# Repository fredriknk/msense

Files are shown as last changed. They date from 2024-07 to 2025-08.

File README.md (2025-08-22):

# Methanesense

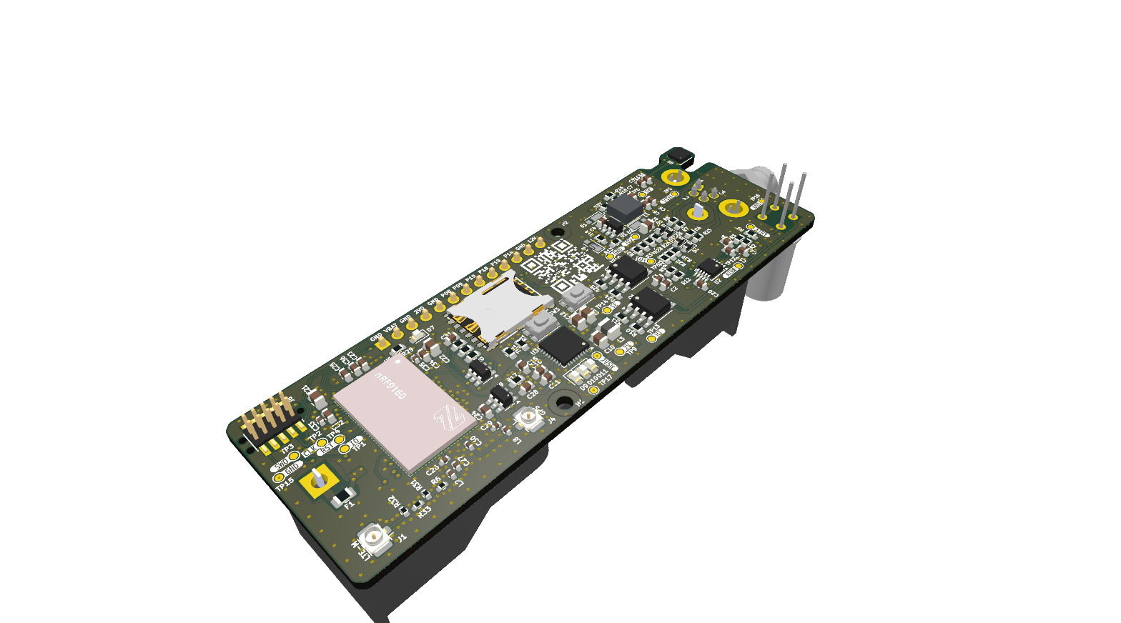
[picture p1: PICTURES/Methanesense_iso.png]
HEADER
 <!-- 3D rendered pretty view -->

Open Source hardware kicad source files for a NRF9160 based methane sensor utilizing MOX sensor.

Low power design with about 60ua average current consumption measuring Methane, temp, pressure and humidity every 30 seconds, averaging values over 5 minute samples, and transmitting 11 readings every 55 minutes. estimated battery life is 4.5 years from a 3200mah  18650 liion cell

It has an option for a GPS if necessary, but this will cause reduced battery life. 

[Assembly IBOM](https://htmlpreview.github.io/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) <!-- Interactive BOM PDF -->

[PCB layout](./DOCUMENTATION/Methanesense_board_prints.pdf) <!-- PDFs of boards -->

[SCHEMATIC](./DOCUMENTATION/Methanesense_schematic.pdf) <!-- Schematic PDFs -->

## FRONT
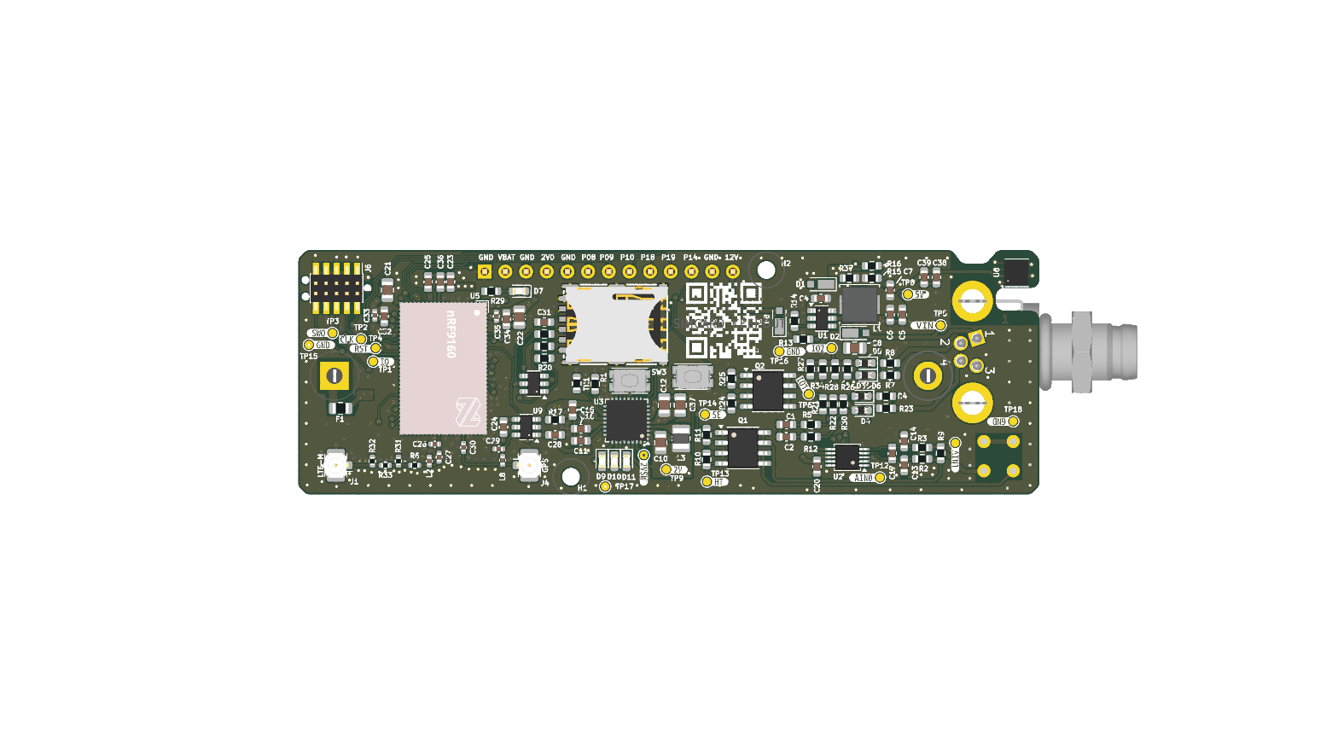
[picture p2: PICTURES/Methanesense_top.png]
Front


## BACK
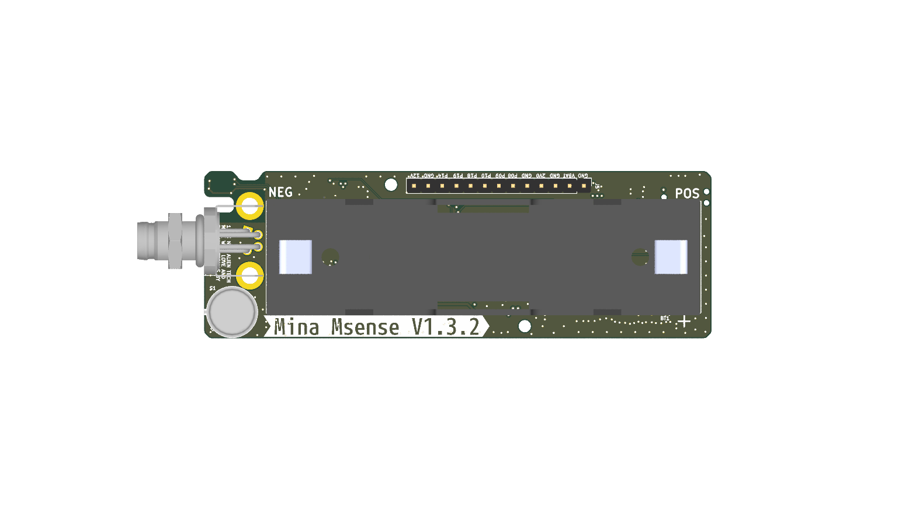
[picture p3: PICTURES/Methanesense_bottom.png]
Back


## SIDE
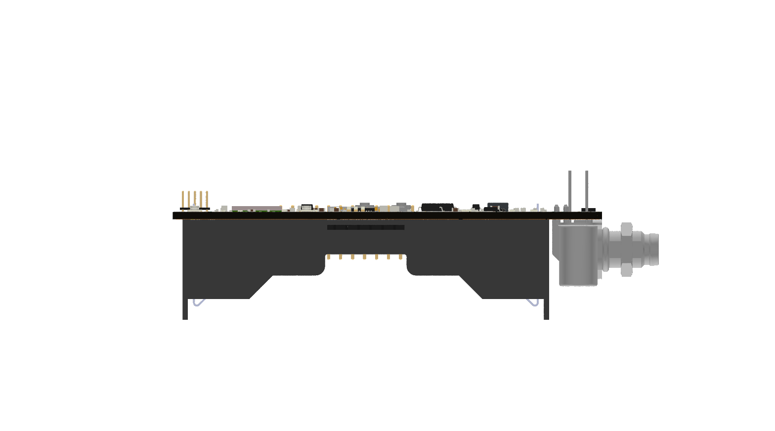
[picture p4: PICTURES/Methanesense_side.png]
Side


## Enclosure
Enclosure proposal. Simple 3d printed design snap lock, potential for epoxy fill for moisture resistance. But for now i just coat them in PLASTIK 70 conformal coating by Kontakt Chemie. DO REMEMBER TO SEAL SENSOR HOLES!!!

When 3d printing the enclosure, modify the two boxes in the sensor holes to be printed with gyroid infill with no walls or top/bottom to create the mesh. Enclosure files are in the [3D_MODEL](./3D_MODEL/) folder.

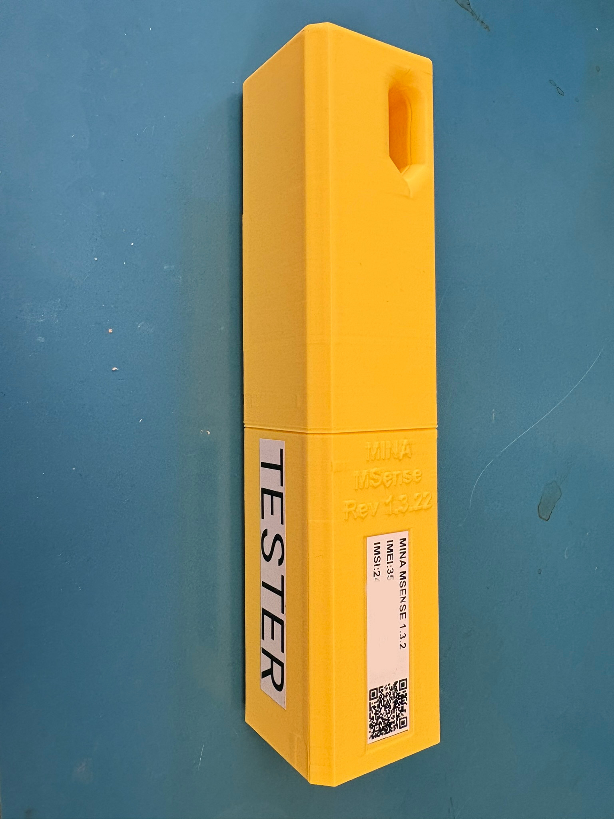
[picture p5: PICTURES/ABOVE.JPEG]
Enclosure

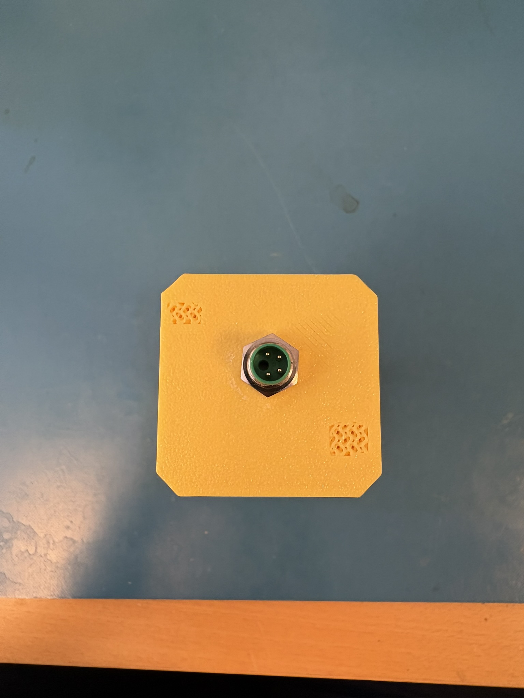
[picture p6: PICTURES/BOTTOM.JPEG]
Bottom_enc


## Documentation

[NRF9160SOC](./DOCUMENTATION/Datasheets/nRF9160_PS_v2.0.pdf)

[ADC](./DOCUMENTATION/Datasheets/ads1113.pdf)

[Temp/press/humidity sensor](./DOCUMENTATION/Datasheets/bst-bme680-ds001.pdf)

[Powersupply PMIC](./DOCUMENTATION/Datasheets/nPM1300_PS_v1.0.pdf)

[MOX Sensor](./DOCUMENTATION/Datasheets/tgs8410_product_infomation(en)_rev05.pdf)

# Before major commmits
Remember to run generate_outputs.bat/sh
to update the outputs and pictures.
readmetemplate

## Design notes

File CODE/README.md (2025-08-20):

The rust firmware for the sensor is located in the [Msense-firmware](https://github.com/fredriknk/msense-firmware) repository.

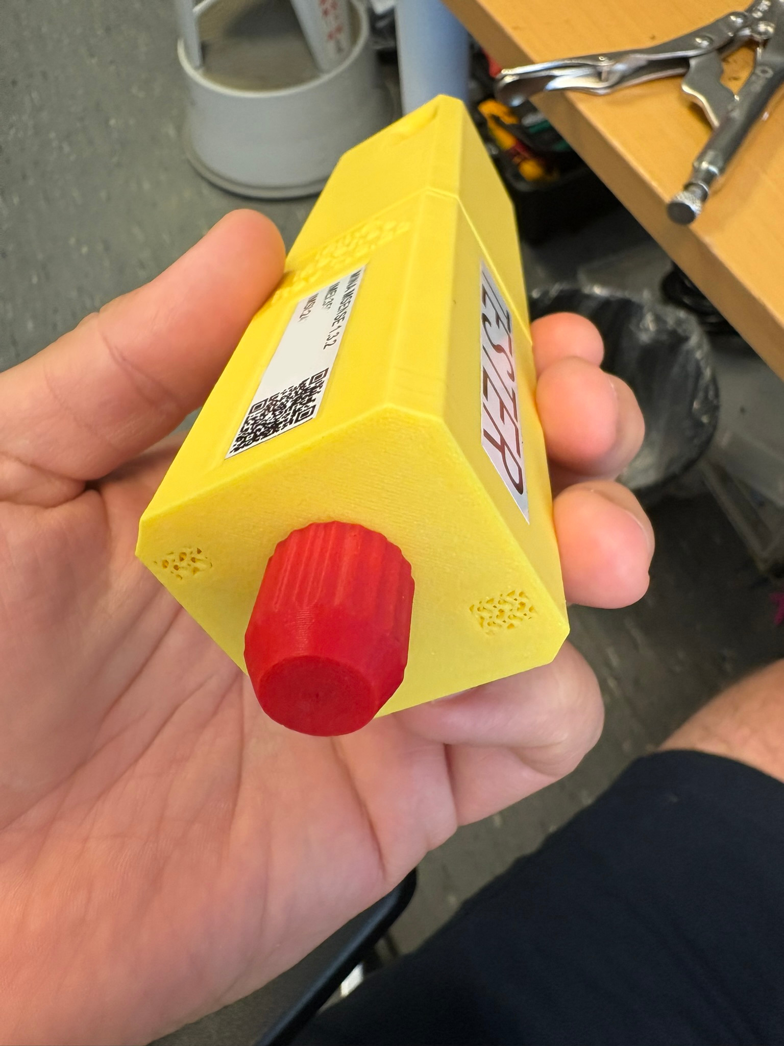
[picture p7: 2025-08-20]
PICTURES/CAP.JPEG

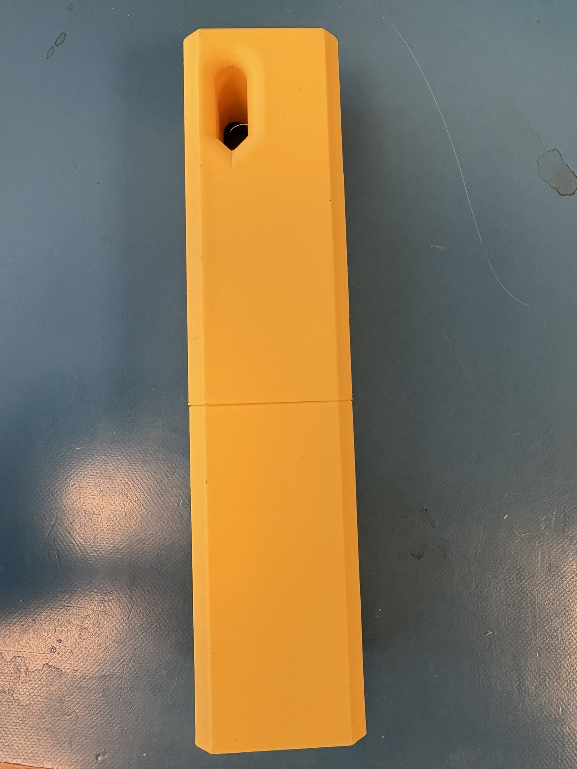
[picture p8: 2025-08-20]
PICTURES/SIDE.JPEG

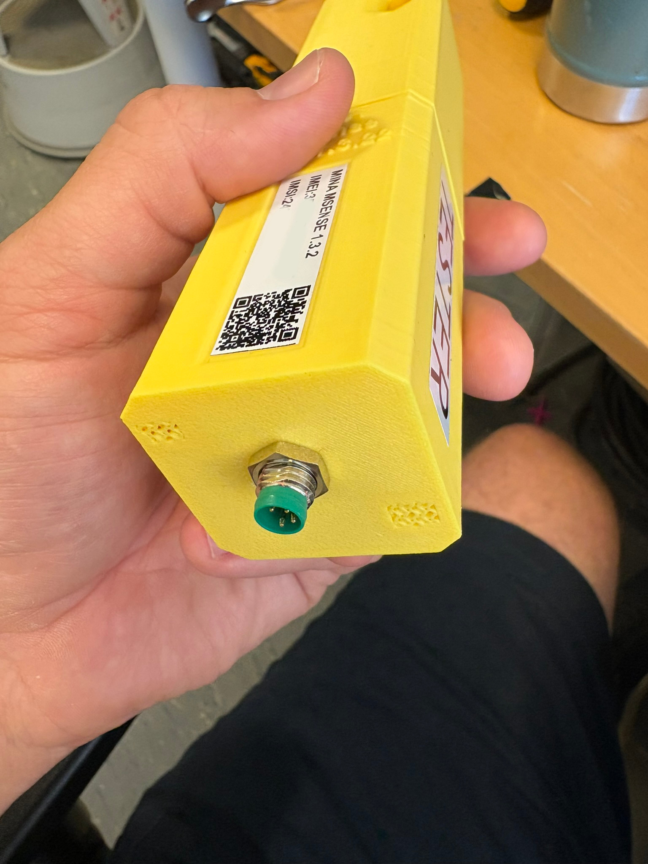
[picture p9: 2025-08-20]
PICTURES/CONNECTOR.JPEG

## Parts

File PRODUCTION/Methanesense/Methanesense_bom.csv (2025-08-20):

Refs | Value | Footprint | Qty | Manufacturer | MPN | Datasheet | DNP
AE1 | 2361492-1 |  | 1 |  | 2361492-1 | ~ | DNP
AE2 | YCGO009AA |  | 1 |  |  | ~ | DNP
BAT1 | 18650-3500mAH |  | 1 |  |  | ~ | DNP
BT1 | BH-18650-PC2 | Methanesense:BatteryHolder_MPD_BH-18650-PC2 | 1 |  | BH-18650-PC2 | ~
C1,C2,C4,C13,C14,C32,C34,C36,C38 | 0.1uF | Capacitor_SMD:C_0603_1608Metric | 9 |  |  | ~
C5-C7,C15,C23,C25 | 4.7uF | Capacitor_SMD:C_0603_1608Metric | 6 |  |  | ~
C8 | 2.2uF | Capacitor_SMD:C_0805_2012Metric | 1 |  |  | ~
C10,C12,C37 | 10uF | Capacitor_SMD:C_0805_2012Metric | 3 |  |  | ~
C11,C16,C17,C20,C28,C31,C39 | 1uF | Capacitor_SMD:C_0603_1608Metric | 7 |  |  | ~ | DNP
C21,C22 | 47uF | Capacitor_SMD:C_0805_2012Metric | 2 |  |  | ~
C24 | 1nF | Capacitor_SMD:C_0603_1608Metric | 1 |  |  | ~
C26,C27,C33,C35 | 15pF | Methanesense:C_0402_1005Metric_Sqr | 4 |  | VJ0402D150FXCAJ | ~
C29,C30 | 56pF | Methanesense:C_0402_1005Metric_Sqr | 2 |  | CBR04C560F1GAC | ~
D1,D2,D8 | MSS1P3L-M3/89A | Diode_SMD:D_MicroSMP_AK | 3 |  | MSS1P3L-M3/89A | ~
D3-D6 | SD0603S040S0R2 | Diode_SMD:D_0603_1608Metric | 4 |  | SD0603S040S0R2 | ~ | DNP
D7 | LG L29K-G2J1-24-Z | LED_SMD:LED_0603_1608Metric | 1 |  | LG L29K-G2J1-24-Z | https://look.ams-osram.com/m/19ee86b3ae0ee95b/original/LG-L29K.pdf
D9-D11 | LED | LED_SMD:LED_0603_1608Metric | 3 |  | LG L29K-G2J1-24-Z | ~
F1 | 0805L110WR | Fuse:Fuse_0805_2012Metric | 1 |  | 0805L110WR | ~
J1,J4 | HIROSE ELECTRIC U.FL-R-SMT-1 | Methanesense:U.FL_Hirose_U.FL-R-SMT-1_Vertical | 2 |  | U.FL-R-SMT-1 | ~
J2 | IEC61076-2_M8_A-coding_01x04_Receptacle_Shielded | Methanesense:STEWART_SS-12800-004_M8_04_Socket_Right_Angle | 1 |  | SS-12800-004
J3 | 693043020611 | Methanesense:693043020611 | 1 |  | 693043020611
J5 | Conn_01x13_Pin | Connector_PinHeader_2.54mm:PinHeader_1x13_P2.54mm_Vertical | 1 |  |  | ~
J6 | JLINK | esprelay:SEXY_pinpogo | 1 |  | BD125-10-A-0305-0580-L-B | ~
L1 | 22uH | Methanesense:L_Abracon_AMDLA4020S | 1 |  | AMDLA4020S-220MT | ~
L2 | 39NH | Methanesense:C_0402_1005Metric_Sqr | 1 |  | LQW15AN39NJ8ZD | ~
L3 | 2.2uH | Inductor_SMD:L_1008_2520Metric | 1 |  | CVH252009-2R2M | ~
L8 | 68 nH | Methanesense:C_0402_1005Metric_Sqr | 1 |  | LQW15AN68NG0ZD | ~
Q1,Q2 | FDS6898A | Package_SO:SOIC-8_3.9x4.9mm_P1.27mm | 2 |  | FDS6898A | https://www.onsemi.com/pub/Collateral/FDS6892A-D.pdf
R1 | 68k | Resistor_SMD:R_0603_1608Metric | 1 |  |  | ~
R2,R3,R5,R12 | 470R | Resistor_SMD:R_0603_1608Metric | 4 |  |  | ~
R4,R8 | 1k | Resistor_SMD:R_0603_1608Metric | 2 |  |  | ~ | DNP
R6,R31-R33 | 0R | Resistor_SMD:R_0402_1005Metric | 4 |  |  | ~ | DNP
R7,R21,R22,R26-R28,R30,R34,R37 | 0R | Resistor_SMD:R_0603_1608Metric | 9 |  |  | ~ | DNP
R9 | 12k | Resistor_SMD:R_0603_1608Metric | 1 |  |  | ~
R10,R11,R17,R24,R25 | 1M | Resistor_SMD:R_0603_1608Metric | 5 |  |  | ~
R13 | 56k | Resistor_SMD:R_0603_1608Metric | 1 |  |  | ~
R14,R16,R23 | 10k | Resistor_SMD:R_0603_1608Metric | 3 |  |  | ~
R15 | 15k | Resistor_SMD:R_0603_1608Metric | 1 |  |  | ~
R18-R20 | 100R | Resistor_SMD:R_0603_1608Metric | 3 |  |  | ~
R29 | 150R | Resistor_SMD:R_0603_1608Metric | 1 |  |  | ~
S1 | TGS8410 | Methanesense:TGS8410 | 1 |  | TGS8410 | https://www.figarosensor.com/product/docs/tgs8410_product%20information%28fusa%29_rev05.pdf
SW1,SW3 | KMR223NGLFG | Methanesense:SW_Push_1P1T_NO_CK_KMR2 | 2 |  | KMR223GLFG | ~
TH1 | 10k NTC | Resistor_SMD:R_0603_1608Metric | 1 |  | NTCG163JF103FT1 | ~
TP1 | SWDIO | TestPoint:TestPoint_Pad_D1.0mm | 1 |  |  | ~ | DNP
TP2 | SWDCLK | TestPoint:TestPoint_Pad_D1.0mm | 1 |  |  | ~ | DNP
TP3 | SWO | TestPoint:TestPoint_Pad_D1.0mm | 1 |  |  | ~ | DNP
TP4 | RST | TestPoint:TestPoint_Pad_D1.0mm | 1 |  |  | ~ | DNP
TP5 | VIN | TestPoint:TestPoint_Pad_D1.0mm | 1 |  |  | ~ | DNP
TP6 | IO1 | TestPoint:TestPoint_Pad_D1.0mm | 1 |  |  | ~ | DNP
TP7 | IO2 | TestPoint:TestPoint_Pad_D1.0mm | 1 |  |  | ~ | DNP
TP8 | 5V | TestPoint:TestPoint_Pad_D1.0mm | 1 |  |  | ~ | DNP
TP9 | 2V | TestPoint:TestPoint_Pad_D1.0mm | 1 |  |  | ~ | DNP
TP10 | I1 | TestPoint:TestPoint_Pad_D1.0mm | 1 |  |  | ~ | DNP
TP11 | AIN1 | TestPoint:TestPoint_Pad_D1.0mm | 1 |  |  | ~ | DNP
TP12 | AIN0 | TestPoint:TestPoint_Pad_D1.0mm | 1 |  |  | ~ | DNP
TP13 | SEN | TestPoint:TestPoint_Pad_D1.0mm | 1 |  |  | ~ | DNP
TP14 | HEAT | TestPoint:TestPoint_Pad_D1.0mm | 1 |  |  | ~ | DNP
TP15-TP18 | GND | TestPoint:TestPoint_Pad_D1.0mm | 4 |  |  | ~ | DNP
U1 | LV2862XDDC | Package_TO_SOT_SMD:SOT-23-6 | 1 |  | LV2862XLVDDCR | https://www.ti.com/lit/ds/symlink/lv2862.pdf
U2 | ADS1115IDGST | Package_SO:TSSOP-10_3x3mm_P0.5mm | 1 |  | ADS1115IDGSR | http://www.ti.com/lit/ds/symlink/ads1113.pdf
U3 | nPM1300-QEXX | Methanesense:QFN-32-1EP_5x5mm_P0.5mm_EP3.6x3.6mm_ThermalVias | 1 |  | nPM1300-QEAA-R7 | https://docs.nordicsemi.com/bundle/ps_npm1300
U5 | nRF9160-SICA | Methanesense:LGA_9160_16.0x10.5mm | 1 |  | nRF9160-SICA-B1A-R7 | https://docs.nordicsemi.com/bundle/ps_nrf9160/page/nRF9160_html5_keyfeatures.html
U6 | BME680 | Package_LGA:Bosch_LGA-8_3x3mm_P0.8mm_ClockwisePinNumbering | 1 |  | BME680 | https://ae-bst.resource.bosch.com/media/_tech/media/datasheets/BST-BME680-DS001.pdf
U8 | USBLC6-4SC6 | Package_TO_SOT_SMD:SOT-23-6 | 1 |  | USBLC6-4SC6 | https://www.st.com/resource/en/datasheet/usblc6-4.pdf
U9 | TPS22917DBV | Package_TO_SOT_SMD:SOT-23-6 | 1 |  | TPS22917DBVR | http://www.ti.com/lit/ds/symlink/tps22917.pdf

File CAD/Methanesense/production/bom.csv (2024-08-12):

Designator | Footprint | Quantity | Value | LCSC Part #
AE1 | XCVR_NN02-220 | 1 | NN02-220 | NN02-220
C1, C2 | 0603 | 2 | 1.7pF | GJM1555C1H1R7WB01
C10, C12, C37 | 0805 | 3 | 10uF
C11, C20, C28, C31, C39, C7, C8, C9 | 0603 | 8 | 1uF
C13, C14, C19, C32, C34, C36, C38 | 0603 | 7 | 0.1uF
C15 | 0603 | 1 | 4.7uF
C16 | 0603 | 1 | 1uF
C21, C22 | 0805 | 2 | 47uF
C23, C25 | 0603 | 2 | 4.7uF
C24 | 0603 | 1 | 1nF
C26, C27, C33, C35 | 0402 | 4 | 15pF | VJ0402D150FXCAJ
C29, C30 | 0402 | 2 | 56pF | CBR04C560F1GAC
C3, C6 | 0603 | 2 | 47pF
C4 | 0603 | 1 | 8.5pF | GJM1555C1H8R5WB01
D10, D11, D5, D6, D9 | 0603 | 5 | LED | LG L29K-G2J1-24-Z
F1 | 0805 | 1 | 0805L110WR | 0805L110WR
J1 | USB_C_Receptacle_HCTL_HC-TYPE-C-16P-01A | 1 | USB_C_Receptacle_USB2.0_14P | 12402012E212A
J3 | 693043020611 | 1 | 693043020611 | 693043020611
J4 | U.FL_Hirose_U.FL-R-SMT-1_Vertical | 1 | HIROSE ELECTRIC U.FL-R-SMT-1 | U.FL-R-SMT-1
L1 | 0603 | 1 | 2.3nH | LQW15AN2N3G80
L2 | 0402 | 1 | 39NH | LQW15AN39NJ8ZD
L3 | 1008 | 1 | 2.2uH | CVH252009-2R2M
L5 | 0603 | 1 | 7.5NH | LQW15AN7N5G80
L6 | 0603 | 1 | 1.6nH | LQW15AN1N6C80
L8 | 0402 | 1 | 68 nH | LQW15AN68NG0ZD
Q1, Q2 | SOIC-8_3.9x4.9mm_P1.27mm | 2 | FDS6898A | FDS6898A
R1 | 0603 | 1 | 68k
R10, R11, R17, R24, R25 | 0603 | 5 | 1M
R18, R19, R20, R22, R23 | 0603 | 5 | 100R
R2, R3 | 0603 | 2 | 470R
R5 | 0603 | 1 | 0R
SW3 | SW_Push_1P1T_NO_CK_KMR2 | 1 | KMR223NGLFG | KMR223NGLFG
TH1 | 0603 | 1 | 10k NTC | NTCG163JF103FT1
U2 | TSSOP-10_3x3mm_P0.5mm | 1 | ADS1115IDGS | ADS1115IDGS
U3 | QFN-32-1EP_5x5mm_P0.5mm_EP3.6x3.6mm_ThermalVias | 1 | nPM1300-QEXX | nPM1300-QEAA-R7
U4 | SOT-23-5 | 1 | AP7331-20WG-7 | AP7331-20WG-7
U5 | LGA_9160_16.0x10.5mm | 1 | nRF9160-SICA | nRF9160-SICA-B1A-R7
U6 | Bosch_LGA-8_3x3mm_P0.8mm_ClockwisePinNumbering | 1 | BME680 | BME680
U7 | QFN-16-1EP_4x4mm_P0.65mm_EP2.1x2.1mm | 1 | FT230XQ | FT230XQ
U8 | SOT-23-6 | 1 | USBLC6-4SC6 | USBLC6-4SC6
U9 | SOT-23-6 | 1 | TPS22917DBV | TPS22917DBVR

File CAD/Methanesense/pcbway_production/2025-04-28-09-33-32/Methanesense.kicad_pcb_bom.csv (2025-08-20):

Designator | Quantity | Value | Footprint | Package | MPN | DNP | Mount_Type | Description | MF | Description_1 | MOUNT | IR | Check_prices | VALUE | Price | PART-NUMBER | SnapEDA_Link | DATASHEET-URL | MP | WORKING-VOLTAGE | PINS | TYPE | GERDER | Availability
BT1 | 1 | BH-18650-PC2 | BatteryHolder_MPD_BH-18650-PC2 |  | BH-18650-PC2 |  | tht | Single-cell battery
C1, C13, C14, C2, C32, C34, C36, C38, C4 | 9 | 0.1uF | C_0603_1608Metric |  |  |  | smt | Unpolarized capacitor
C10, C12, C37 | 3 | 10uF | C_0805_2012Metric |  |  |  | smt | Unpolarized capacitor
C11, C16, C20, C28, C31, C39 | 6 | 1uF | C_0603_1608Metric |  |  |  | smt | Unpolarized capacitor
C15, C23, C25, C5, C6, C7 | 6 | 4.7uF | C_0603_1608Metric |  |  |  | smt | Unpolarized capacitor
C17 | 1 | 1uF | C_0603_1608Metric |  |  | Yes | smt | Unpolarized capacitor
C21, C22 | 2 | 47uF | C_0805_2012Metric |  |  |  | smt | Unpolarized capacitor
C24 | 1 | 1nF | C_0603_1608Metric |  |  |  | smt | Unpolarized capacitor
C26, C27, C33, C35 | 4 | 15pF | C_0402_1005Metric_Sqr |  | VJ0402D150FXCAJ |  | smt | RF
C29, C30 | 2 | 56pF | C_0402_1005Metric_Sqr |  | CBR04C560F1GAC |  | smt | RF
C8 | 1 | 2.2uF | C_0805_2012Metric |  |  |  | smt | Unpolarized capacitor
D1, D2, D8 | 3 | MSS1P3L-M3/89A | D_MicroSMP_AK |  | MSS1P3L-M3/89A |  | smt | Schottky diode
D10, D11, D9 | 3 | LED | LED_0603_1608Metric |  | LG L29K-G2J1-24-Z |  | smt | Light emitting diode
D3, D4, D6 | 3 | SD0603S040S0R2 | D_0603_1608Metric |  | SD0603S040S0R2 |  | smt | Schottky diode
D5 | 1 | SD0603S040S0R2 | D_0603_1608Metric |  | SD0603S040S0R2 | Yes | smt | Schottky diode
D7 | 1 | LG L29K-G2J1-24-Z | LED_0603_1608Metric |  | LG L29K-G2J1-24-Z |  | smt | LED Green
F1 | 1 | 0805L110WR | Fuse_0805_2012Metric |  | 0805L110WR |  | smt | Resettable fuse, polymeric positive temperature coefficient
J1, J4 | 2 | HIROSE ELECTRIC U.FL-R-SMT-1 | U.FL_Hirose_U.FL-R-SMT-1_Vertical |  | U.FL-R-SMT-1 |  | smt | coaxial connector (BNC, SMA, SMB, SMC, Cinch/RCA, LEMO, ...)
J2 | 1 | IEC61076-2_M8_A-coding_01x04_Receptacle_Shielded | STEWART_SS-12800-004_M8_04_Socket_Right_Angle |  | SS-12800-004 |  | tht | IEC 61076-2 4 ways shielded M8 A-coding receptacle connector
J3 | 1 | 693043020611 | 693043020611 |  | 693043020611 |  | smt |  | Wurth Electronics | CardConnector_SMT_NanoSIM_Push & Pull_6pins | SMT | 1A | https://www.snapeda.com/parts/693043020611/Wurth+Electronics/view-part/?ref=eda | 693043020611 | None | 693043020611 | https://www.snapeda.com/parts/693043020611/Wurth+Electronics/view-part/?ref=snap | https://www.we-online.com/redexpert/spec/693043020611?ae | 693043020611 | 15V(AC) | 6 | Push & Push | Socket | In Stock
J5 | 1 | Conn_01x13_Pin | PinHeader_1x13_P2.54mm_Vertical |  |  |  | tht | Generic connector, single row, 01x13, script generated
J6 | 1 | JLINK | SEXY_pinpogo |  | BD125-10-A-0305-0580-L-B |  | smt | HEADER DUAL 1.27MM VERT SMT 10PO
L1 | 1 | 22uH | L_Abracon_AMDLA4020S |  | AMDLA4020S-220MT |  | smt | Inductor
L2 | 1 | 39NH | C_0402_1005Metric_Sqr |  | LQW15AN39NJ8ZD |  | smt | 250mA 0.7OHM SMD RF
L3 | 1 | 2.2uH | L_1008_2520Metric |  | CVH252009-2R2M |  | smt
L8 | 1 | 68 nH | C_0402_1005Metric_Sqr |  | LQW15AN68NG0ZD |  | smt | RF
Q1, Q2 | 2 | FDS6898A | SOIC-8_3.9x4.9mm_P1.27mm |  | FDS6898A |  | smt | 9.4A Id, 20V Vds, Dual N-Channel MOSFET , 14mOhm Ron, SO-8
R1 | 1 | 68k | R_0603_1608Metric |  |  |  | smt | Resistor
R10, R11, R17, R24, R25 | 5 | 1M | R_0603_1608Metric |  |  |  | smt | Resistor
R12, R2, R3, R5 | 4 | 470R | R_0603_1608Metric |  |  |  | smt | Resistor
R13 | 1 | 56k | R_0603_1608Metric |  |  |  | smt | Resistor
R14, R16, R23 | 3 | 10k | R_0603_1608Metric |  |  |  | smt | Resistor
R15 | 1 | 15k | R_0603_1608Metric |  |  |  | smt | Resistor
R18, R19, R20 | 3 | 100R | R_0603_1608Metric |  |  |  | smt | Resistor
R21 | 1 | 0R | R_0603_1608Metric |  |  | Yes | smt | Resistor
R22 | 1 | 0R | R_0603_1608Metric |  |  | Yes | smt | Resistor
R26 | 1 | 0R | R_0603_1608Metric |  |  | Yes | smt | Resistor
R27, R30, R37, R7 | 4 | 0R | R_0603_1608Metric |  |  |  | smt | Resistor
R28 | 1 | 0R | R_0603_1608Metric |  |  | Yes | smt | Resistor
R29 | 1 | 150R | R_0603_1608Metric |  |  |  | smt | Resistor
R31 | 1 | 0R | R_0402_1005Metric |  |  | Yes | smt | Resistor
R32 | 1 | 0R | R_0402_1005Metric |  |  | Yes | smt | Resistor
R33, R6 | 2 | 0R | R_0402_1005Metric |  |  |  | smt | Resistor
R34 | 1 | 0R | R_0603_1608Metric |  |  | Yes | smt | Resistor
R4 | 1 | 1k | R_0603_1608Metric |  |  |  | smt | Resistor
R8 | 1 | 1k | R_0603_1608Metric |  |  | Yes | smt | Resistor
R9 | 1 | 12k | R_0603_1608Metric |  |  |  | smt | Resistor
S1 | 1 | TGS8410 | TGS8410 |  | TGS8410 |  | tht | MOX gas sensor
SW1, SW3 | 2 | KMR223NGLFG | SW_Push_1P1T_NO_CK_KMR2 |  | KMR223GLFG |  | smt | Push button switch, generic, two pins
TH1 | 1 | 10k NTC | R_0603_1608Metric |  | NTCG163JF103FT1 |  | smt | Temperature dependent resistor, negative temperature coefficient
TP1 | 1 | SWDIO | TestPoint_Pad_D1.0mm |  |  | Yes | tht | test point
TP10 | 1 | I1 | TestPoint_Pad_D1.0mm |  |  | Yes | tht | test point
TP11 | 1 | AIN1 | TestPoint_Pad_D1.0mm |  |  | Yes | tht | test point
TP12 | 1 | AIN0 | TestPoint_Pad_D1.0mm |  |  | Yes | tht | test point
TP13 | 1 | SEN | TestPoint_Pad_D1.0mm |  |  | Yes | tht | test point
TP14 | 1 | HEAT | TestPoint_Pad_D1.0mm |  |  | Yes | tht | test point
TP15 | 1 | GND | TestPoint_Pad_D1.0mm |  |  | Yes | tht | test point
TP16 | 1 | GND | TestPoint_Pad_D1.0mm |  |  | Yes | tht | test point
TP17 | 1 | GND | TestPoint_Pad_D1.0mm |  |  | Yes | tht | test point
TP18 | 1 | GND | TestPoint_Pad_D1.0mm |  |  | Yes | tht | test point
TP2 | 1 | SWDCLK | TestPoint_Pad_D1.0mm |  |  | Yes | tht | test point
TP3 | 1 | SWO | TestPoint_Pad_D1.0mm |  |  | Yes | tht | test point
TP4 | 1 | RST | TestPoint_Pad_D1.0mm |  |  | Yes | tht | test point
TP5 | 1 | VIN | TestPoint_Pad_D1.0mm |  |  | Yes | tht | test point
TP6 | 1 | IO1 | TestPoint_Pad_D1.0mm |  |  | Yes | tht | test point
TP7 | 1 | IO2 | TestPoint_Pad_D1.0mm |  |  | Yes | tht | test point
TP8 | 1 | 5V | TestPoint_Pad_D1.0mm |  |  | Yes | tht | test point
TP9 | 1 | 2V | TestPoint_Pad_D1.0mm |  |  | Yes | tht | test point
U1 | 1 | LV2862XDDC | SOT-23-6 |  | LV2862XLVDDCR |  | smt | 60V, 0.6A, stepdown, DC/DC converter, 770kHz
U2 | 1 | ADS1115IDGST | TSSOP-10_3x3mm_P0.5mm |  | ADS1115IDGSR |  | smt
U3 | 1 | nPM1300-QEXX | QFN-32-1EP_5x5mm_P0.5mm_EP3.6x3.6mm_ThermalVias |  | nPM1300-QEAA-R7 |  | smt | PMIC, LED Driver, Battery Charger, QFN-32
U5 | 1 | nRF9160-SICA | LGA_9160_16.0x10.5mm |  | nRF9160-SICA-B1A-R7 |  | smt
U6 | 1 | BME680 | Bosch_LGA-8_3x3mm_P0.8mm_ClockwisePinNumbering |  | BME680 |  | smt | 4-in-1 sensor, gas, humidity, pressure, temperature, I2C and SPI interface, 1.71-3.6V, LGA-8
U8 | 1 | USBLC6-4SC6 | SOT-23-6 |  | USBLC6-4SC6 |  | smt | Very low capacitance ESD protection diode, 4 data-line, SOT-23-6
U9 | 1 | TPS22917DBV | SOT-23-6 |  | TPS22917DBVR |  | smt | 1V to 5.5V, 2A, 80mΩ Ultra-Low Leakage Load Switch, SOT23-6

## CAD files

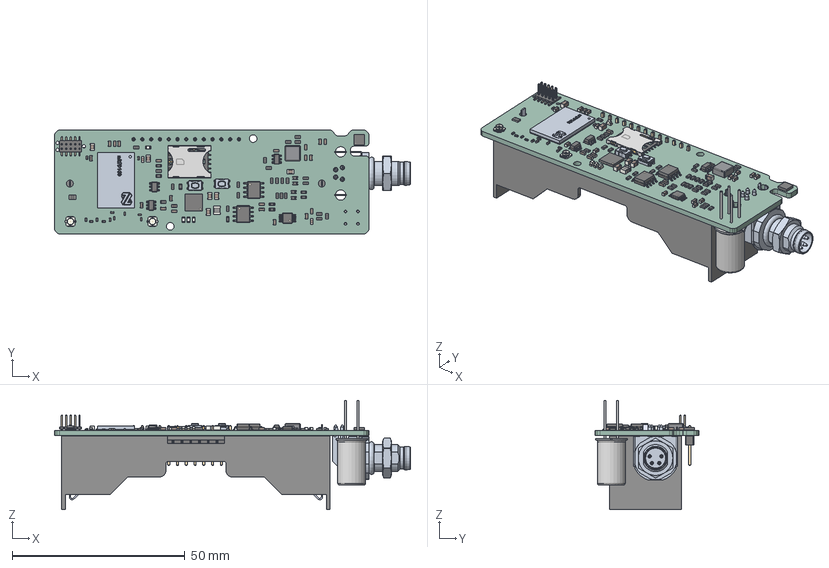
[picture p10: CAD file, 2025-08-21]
3D_MODEL/Methanesense.step
103.0 x 30.0 x 31.6 mm
C_0402_1005Metric x 8
R_0603_1608Metric x 32
SOIC-8_3.9x4.9mm_P1.27mm x 2
C_0603_1608Metric x 23
Bosch_LGA-8_3x3mm_P0.8mm_ClockwisePinNumbering
C_0805_2012Metric x 6
LED_0603_1608Metric x 4
PinHeader_2x05_P1.27mm_Vertical_SMD
KMR231GLFS x 2
R_0402_1005Metric x 4
SOT-23-6 x 3
D_0603_1608Metric x 4
Fuse_0805_2012Metric
U.FL_Hirose_U.FL-R-SMT-1_Vertical x 2
TSSOP-10_3x3mm_P0.5mm
693043020611_SHIELDING
Methanesense 1.55.1
L_Abracon_ASPIAIG-F4020
QFN-32-1EP_5x5mm_P0.5mm_EP3.45x3.45mm
L_1008_2520Metric
TGS8410 v2
BH-18650-PC--3DModel-STEP-56544
SS-12800-004_PART1
SS-12800-004_PART2
SS-12800-004_PART3
SS-12800-004_PART4
PinHeader_1x13_P2.54mm_Vertical
Methanesense_PCB

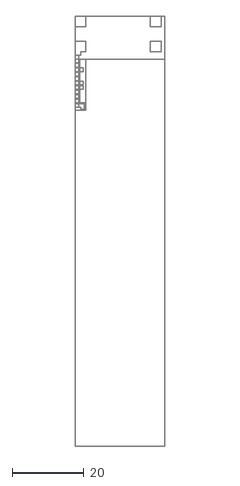
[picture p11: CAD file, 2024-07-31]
DOCUMENTATION/Antennadesign/Top.dxf
25.0 x 120.0

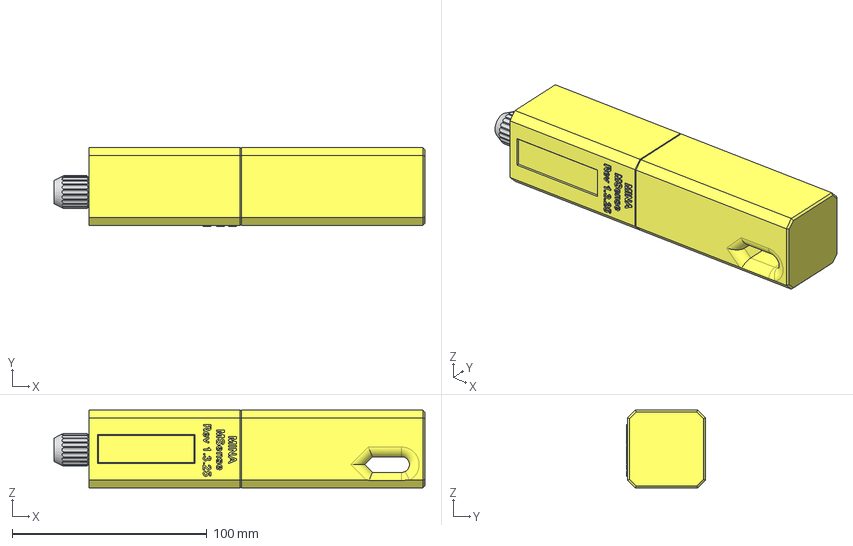
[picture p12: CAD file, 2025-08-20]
3D_MODEL/Enclosure_board_132 v26.step
190.6 x 40.5 x 40.0 mm
Case
m8_plug

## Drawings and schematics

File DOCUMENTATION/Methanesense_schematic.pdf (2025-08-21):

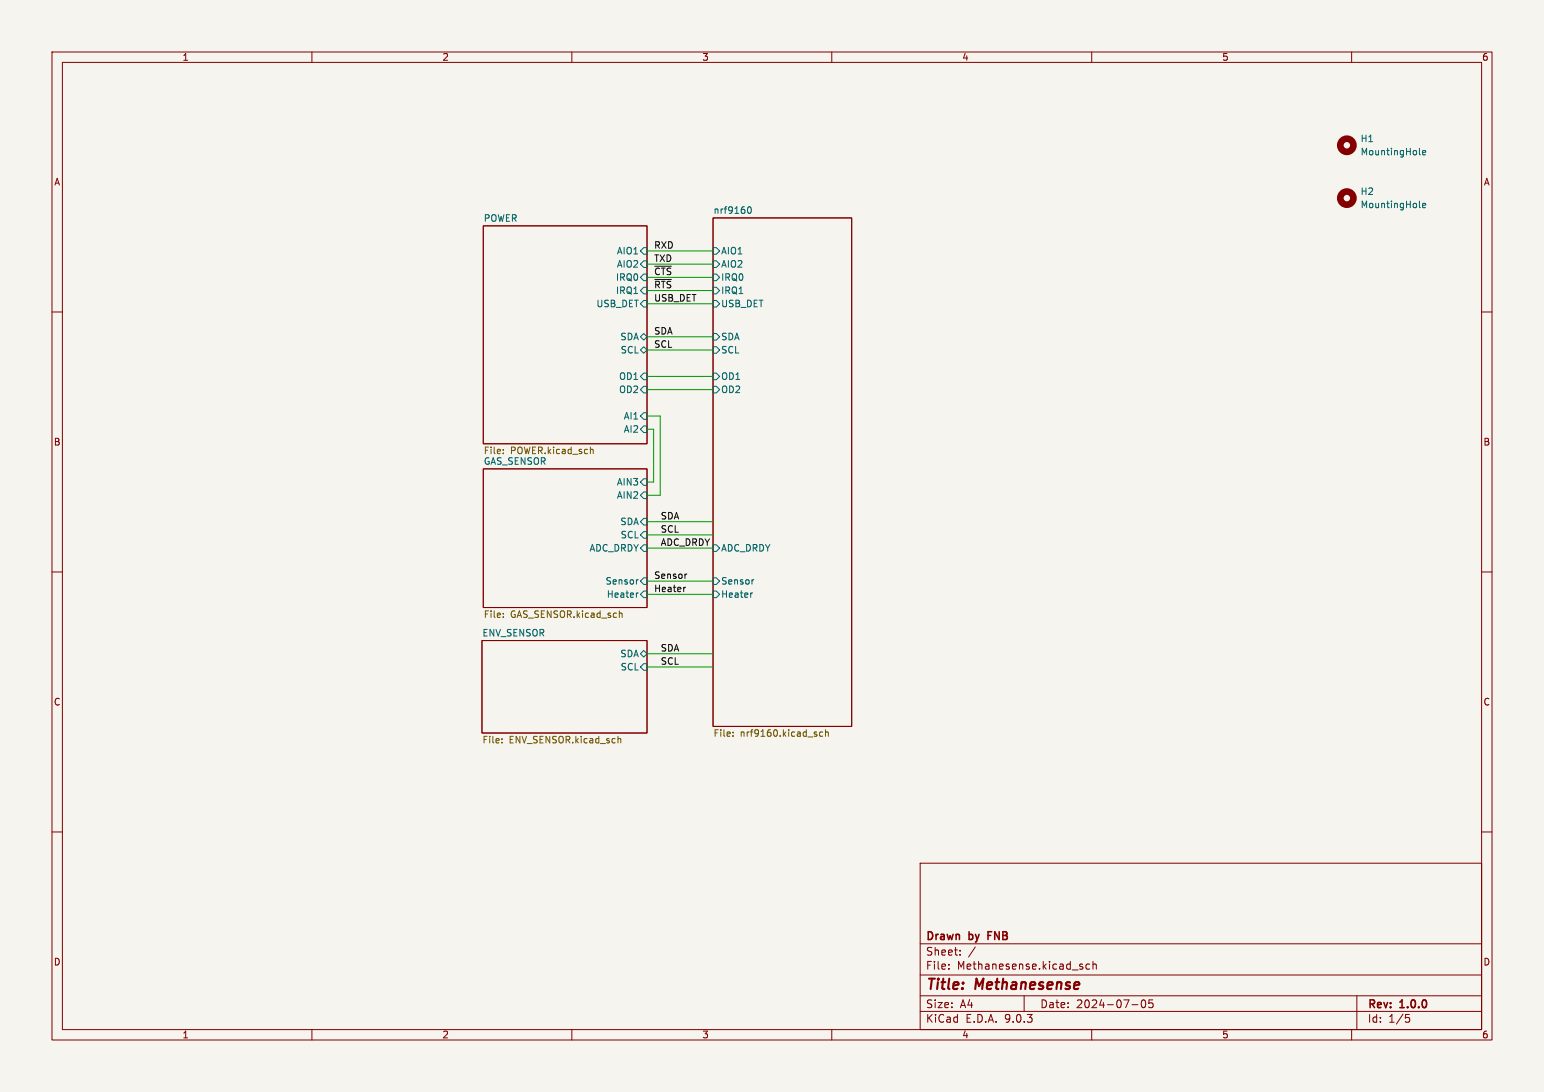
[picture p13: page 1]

H1 MountingHole H2 MountingHole Heater SCL Sensor ~{CTS} SDA USB_DET SCL SCL ADC_DRDY
nrf9160 File: nrf9160.kicad_sch
SDA RXD
SCL USB_DET AI1 AIO1 OD1 AI2 AIO2 OD2
SCL USB_DET OD1 OD2

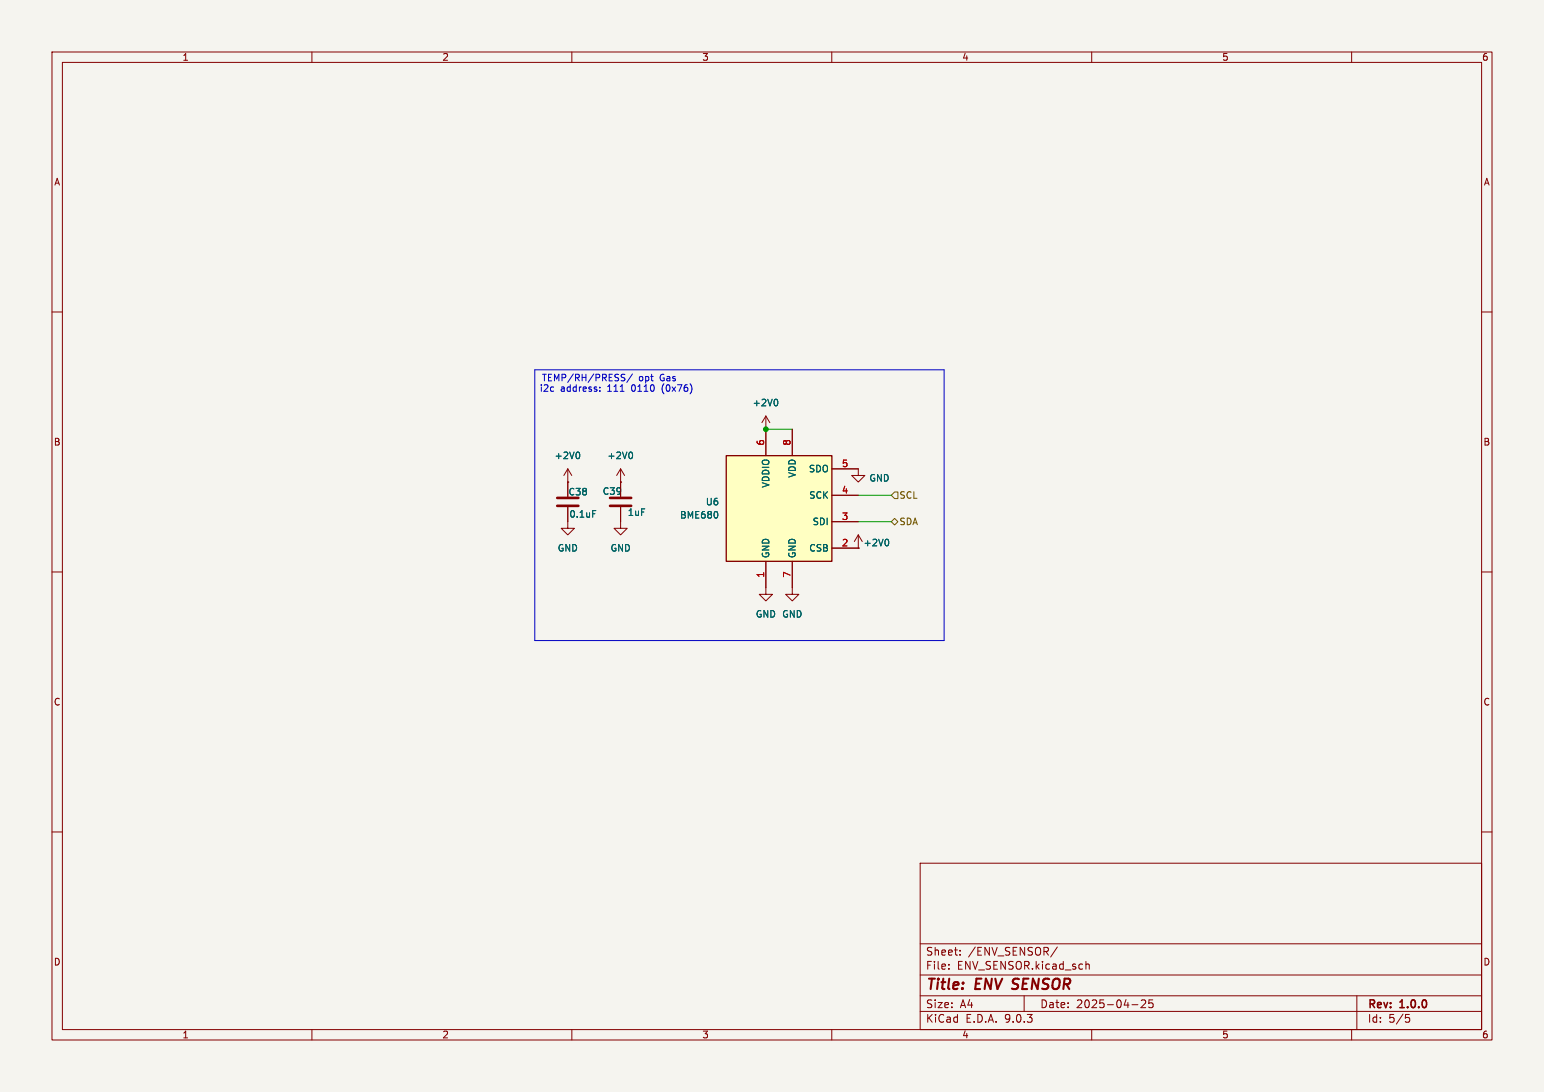
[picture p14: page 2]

7 SDO 5 SCK 4 SDI 3 CSB 2 U6 BME680 +2V0 +2V0 C39

7 SDO 5 SCK 4 SDI 3 CSB 2 +2V0 +2V0 C39

File: ENV_SENSOR.kicad_sch Sheet: /ENV_SENSOR/
Id: 5/5 Title: ENV SENSOR

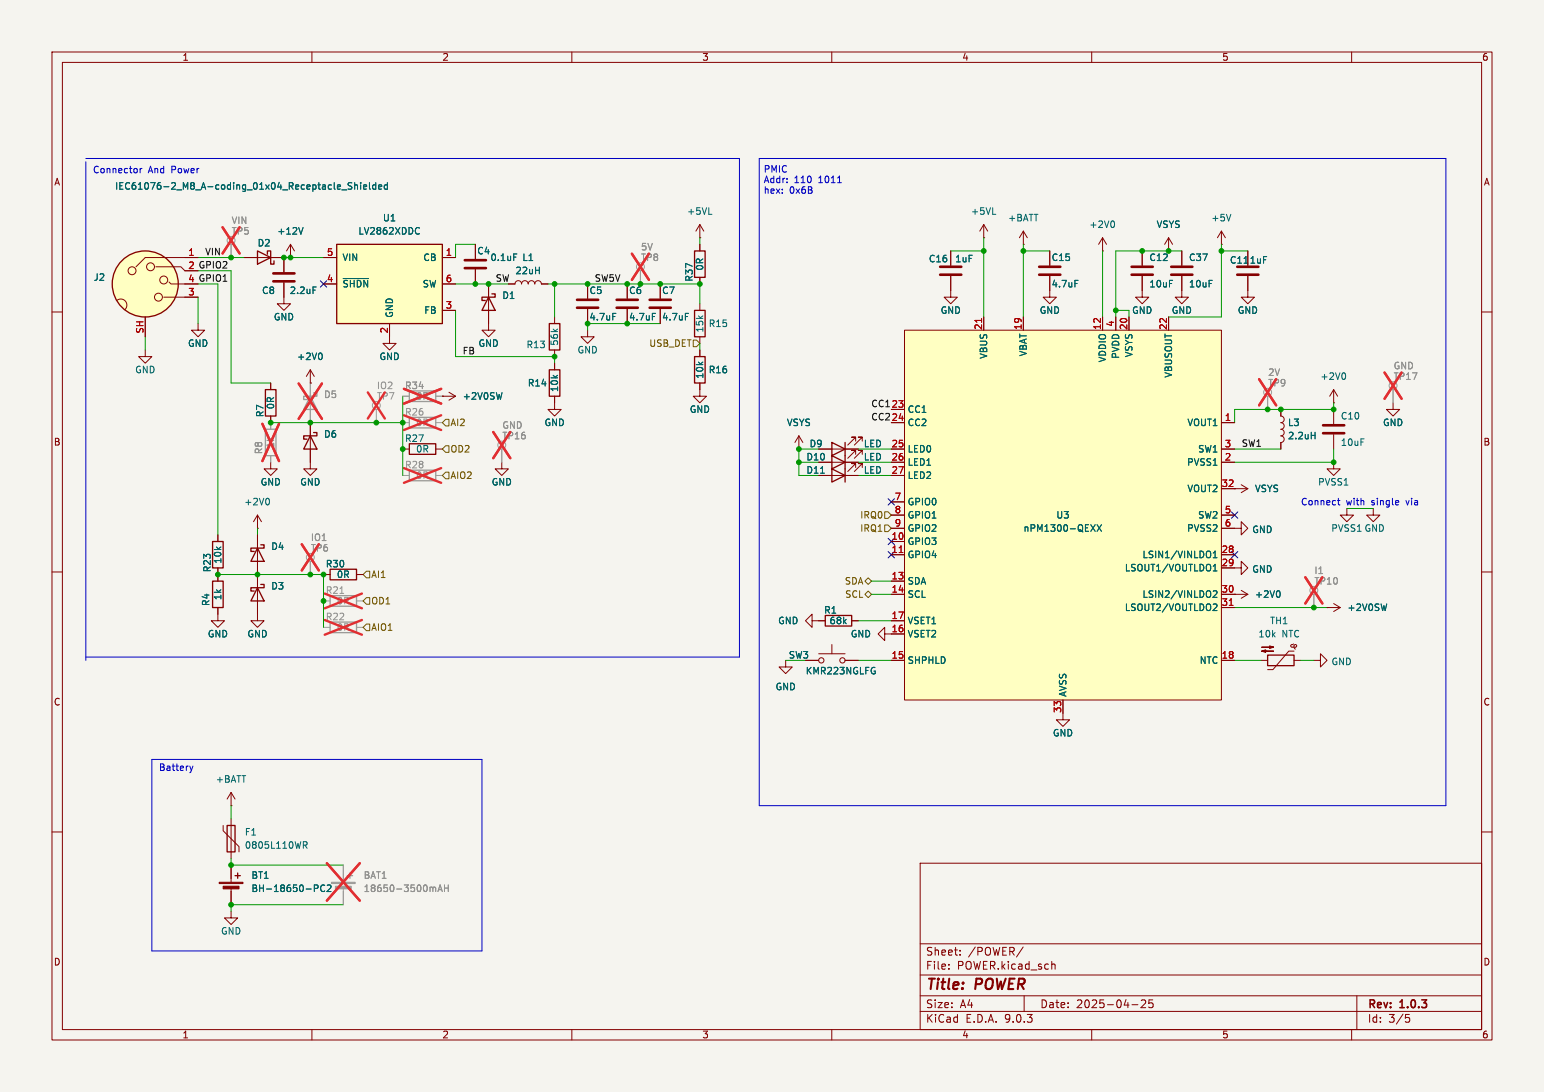
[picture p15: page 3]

File: POWER.kicad_sch Sheet: /POWER/
Id: 3/5 Title: POWER

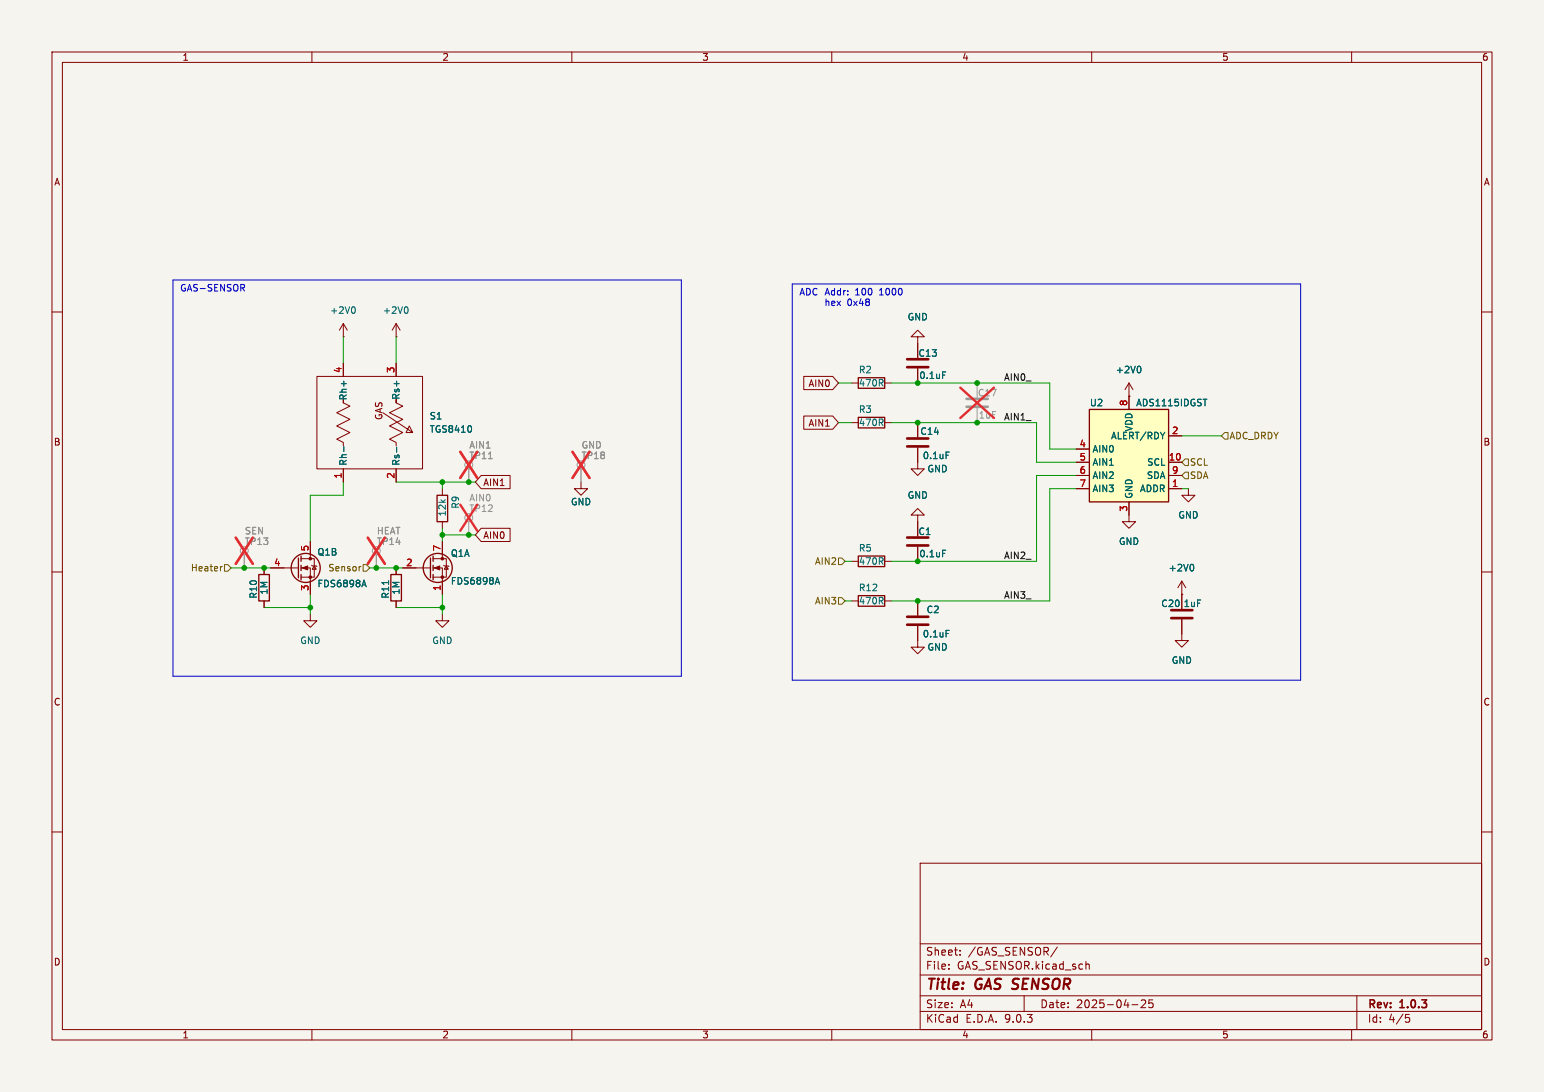
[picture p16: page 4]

3 ALERT/RDY 2 SCL 10 SDA 9 ADDR 1 U2 ADS1115IDGST GND

3 ALERT/RDY 2 SCL 10 SDA 9 ADDR 1 C13

File: GAS_SENSOR.kicad_sch Sheet: /GAS_SENSOR/
Id: 4/5 Title: GAS SENSOR

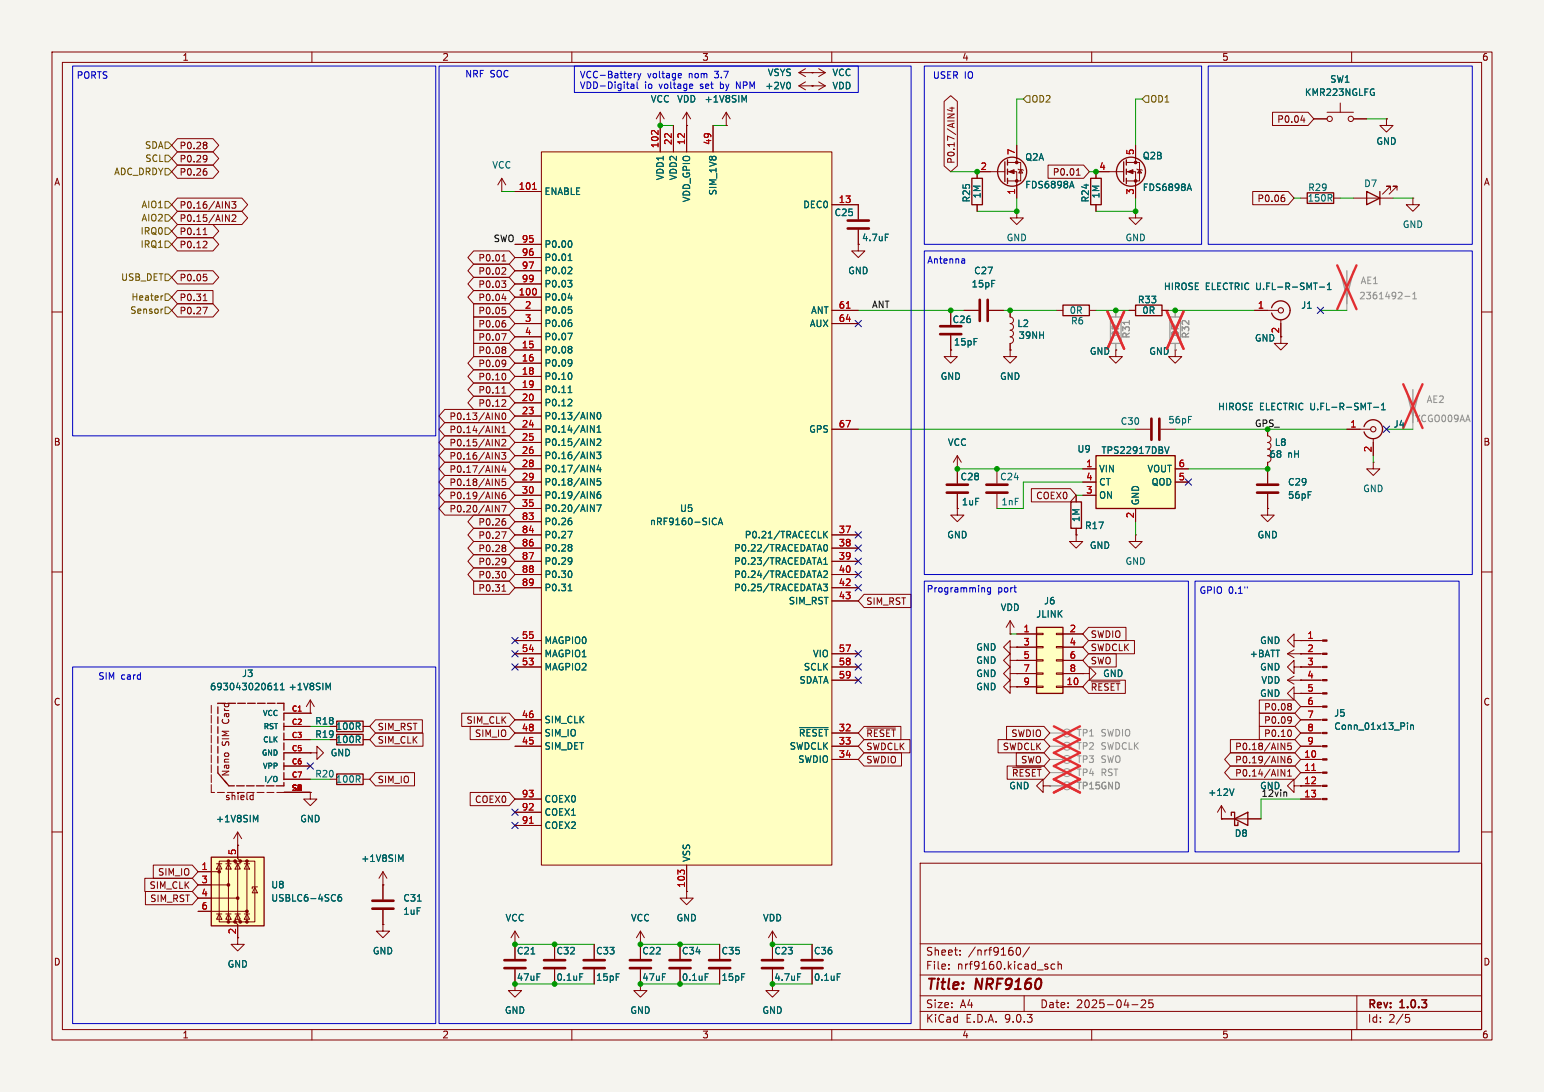
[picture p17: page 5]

GPIO 0.1" Antenna SIM card

J4 HIROSE ELECTRIC U.FL-R-SMT-1

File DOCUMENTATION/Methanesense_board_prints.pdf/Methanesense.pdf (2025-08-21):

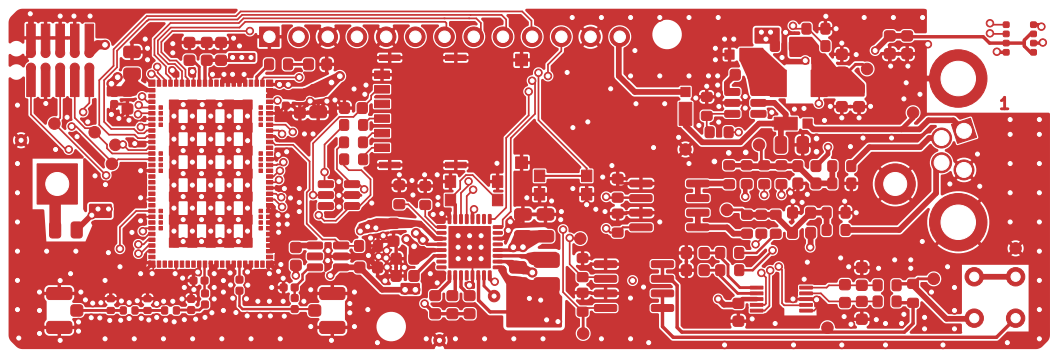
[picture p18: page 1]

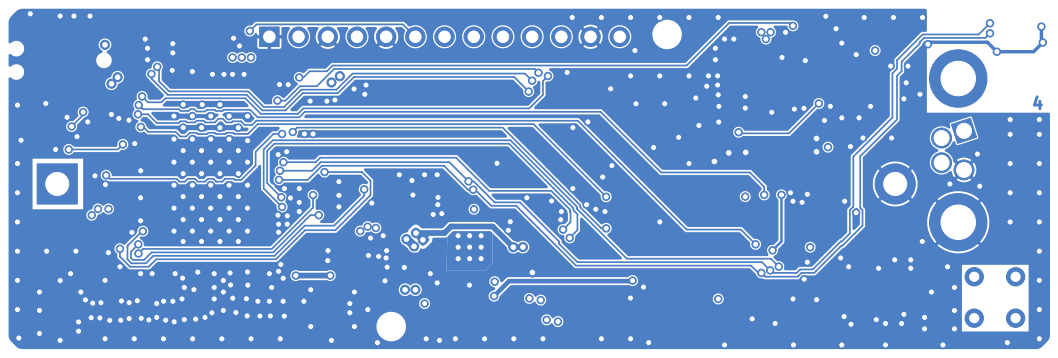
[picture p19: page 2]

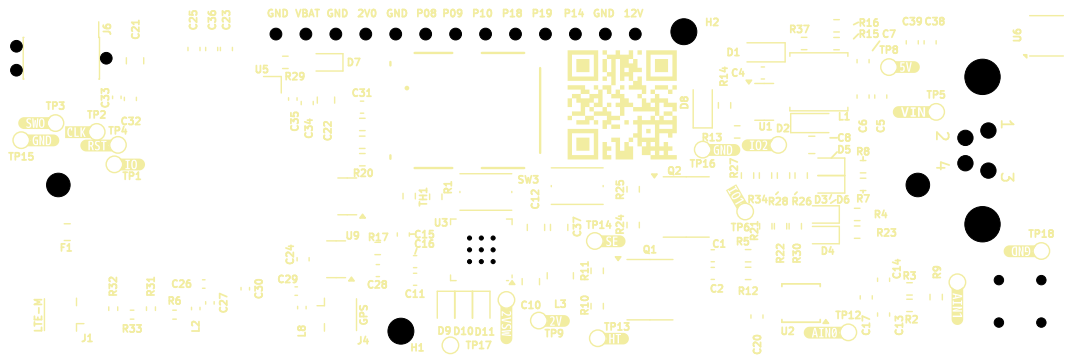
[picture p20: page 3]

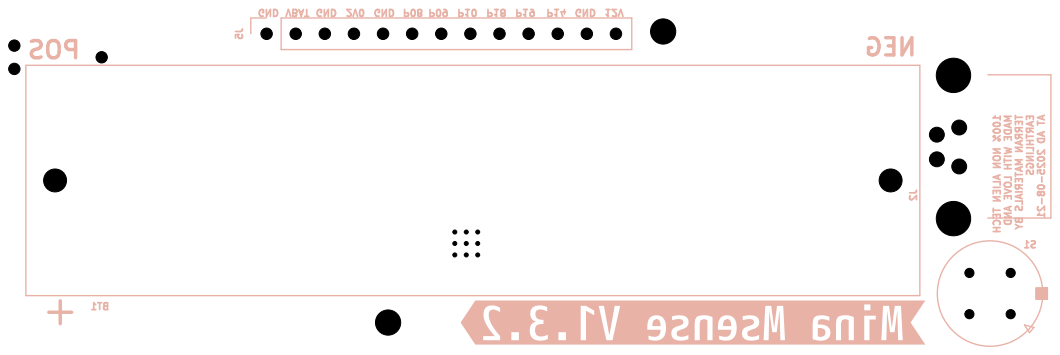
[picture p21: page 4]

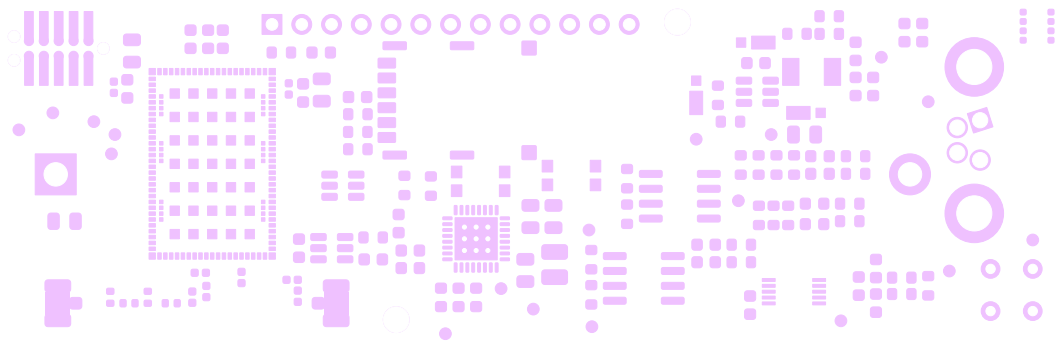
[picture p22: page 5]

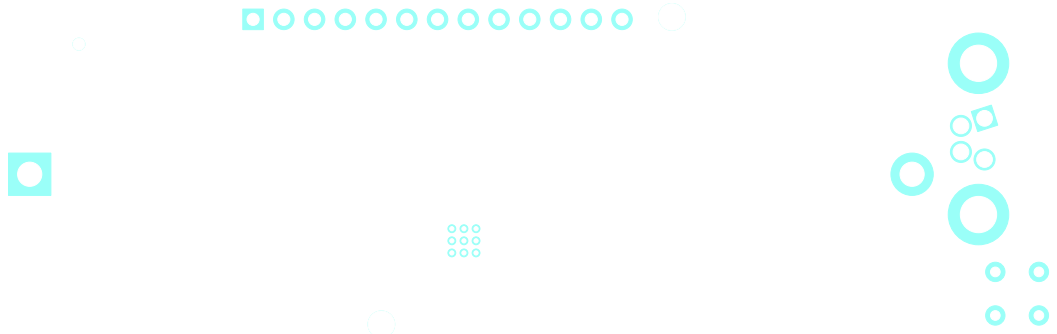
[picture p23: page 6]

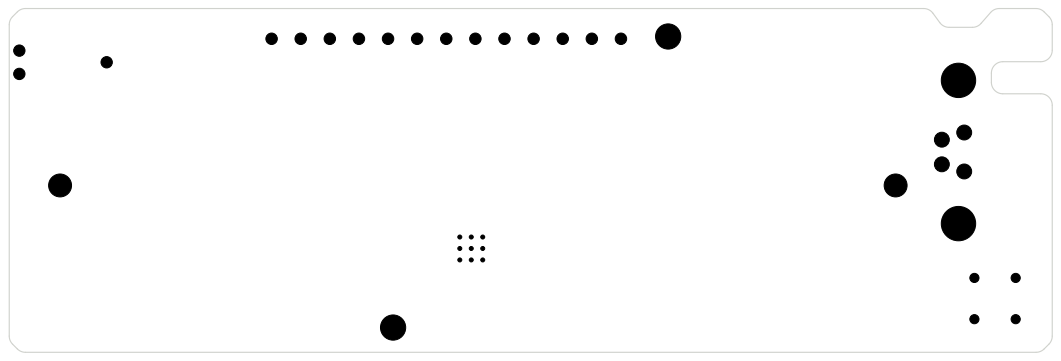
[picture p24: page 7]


F1 HIROSE ELECTRIC U.FL-R-SMT-1 J1



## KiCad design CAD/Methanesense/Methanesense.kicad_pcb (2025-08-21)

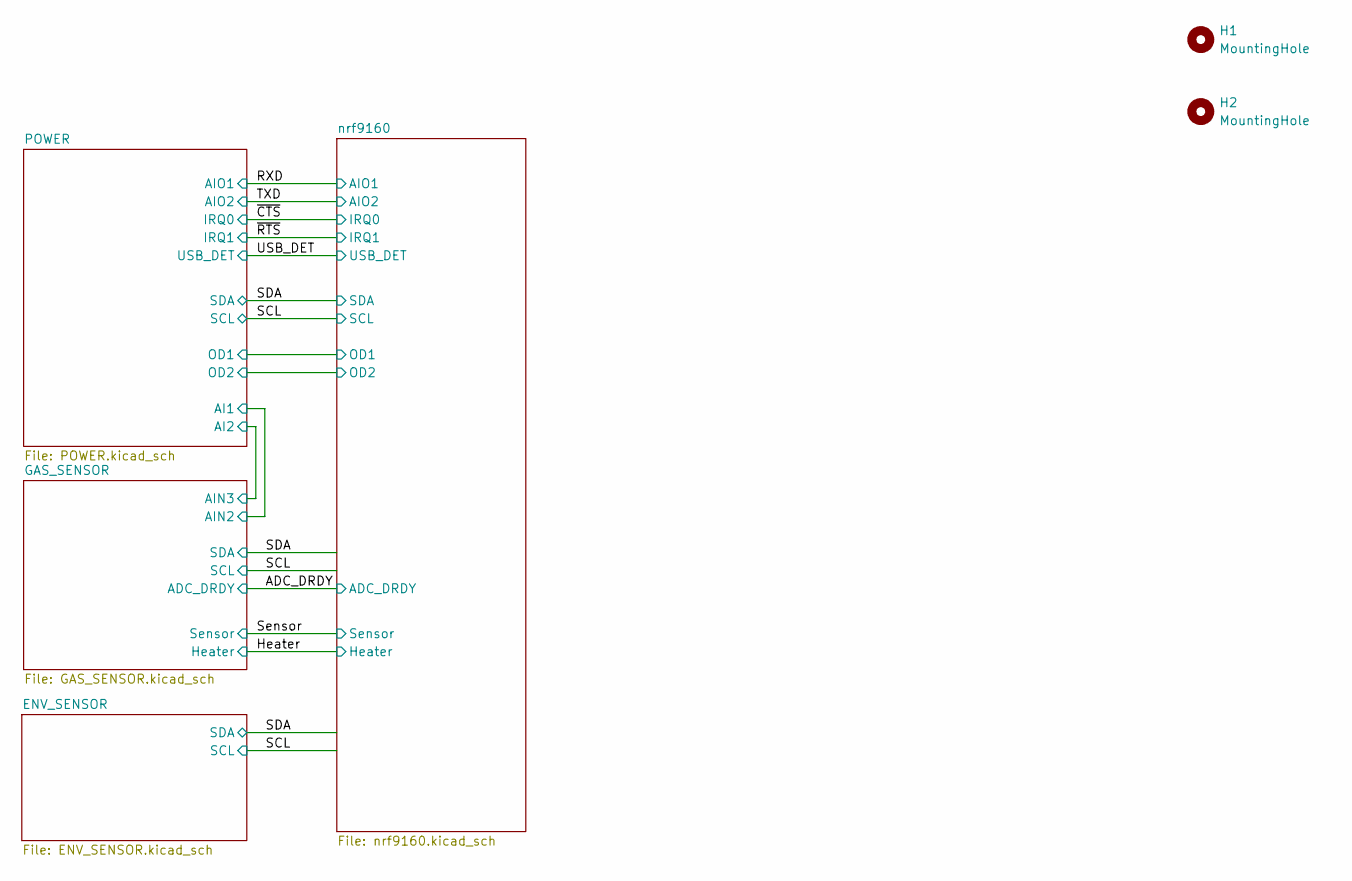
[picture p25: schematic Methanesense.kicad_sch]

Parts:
H1, H2: MountingHole; MountingHole_2.2mm_M2

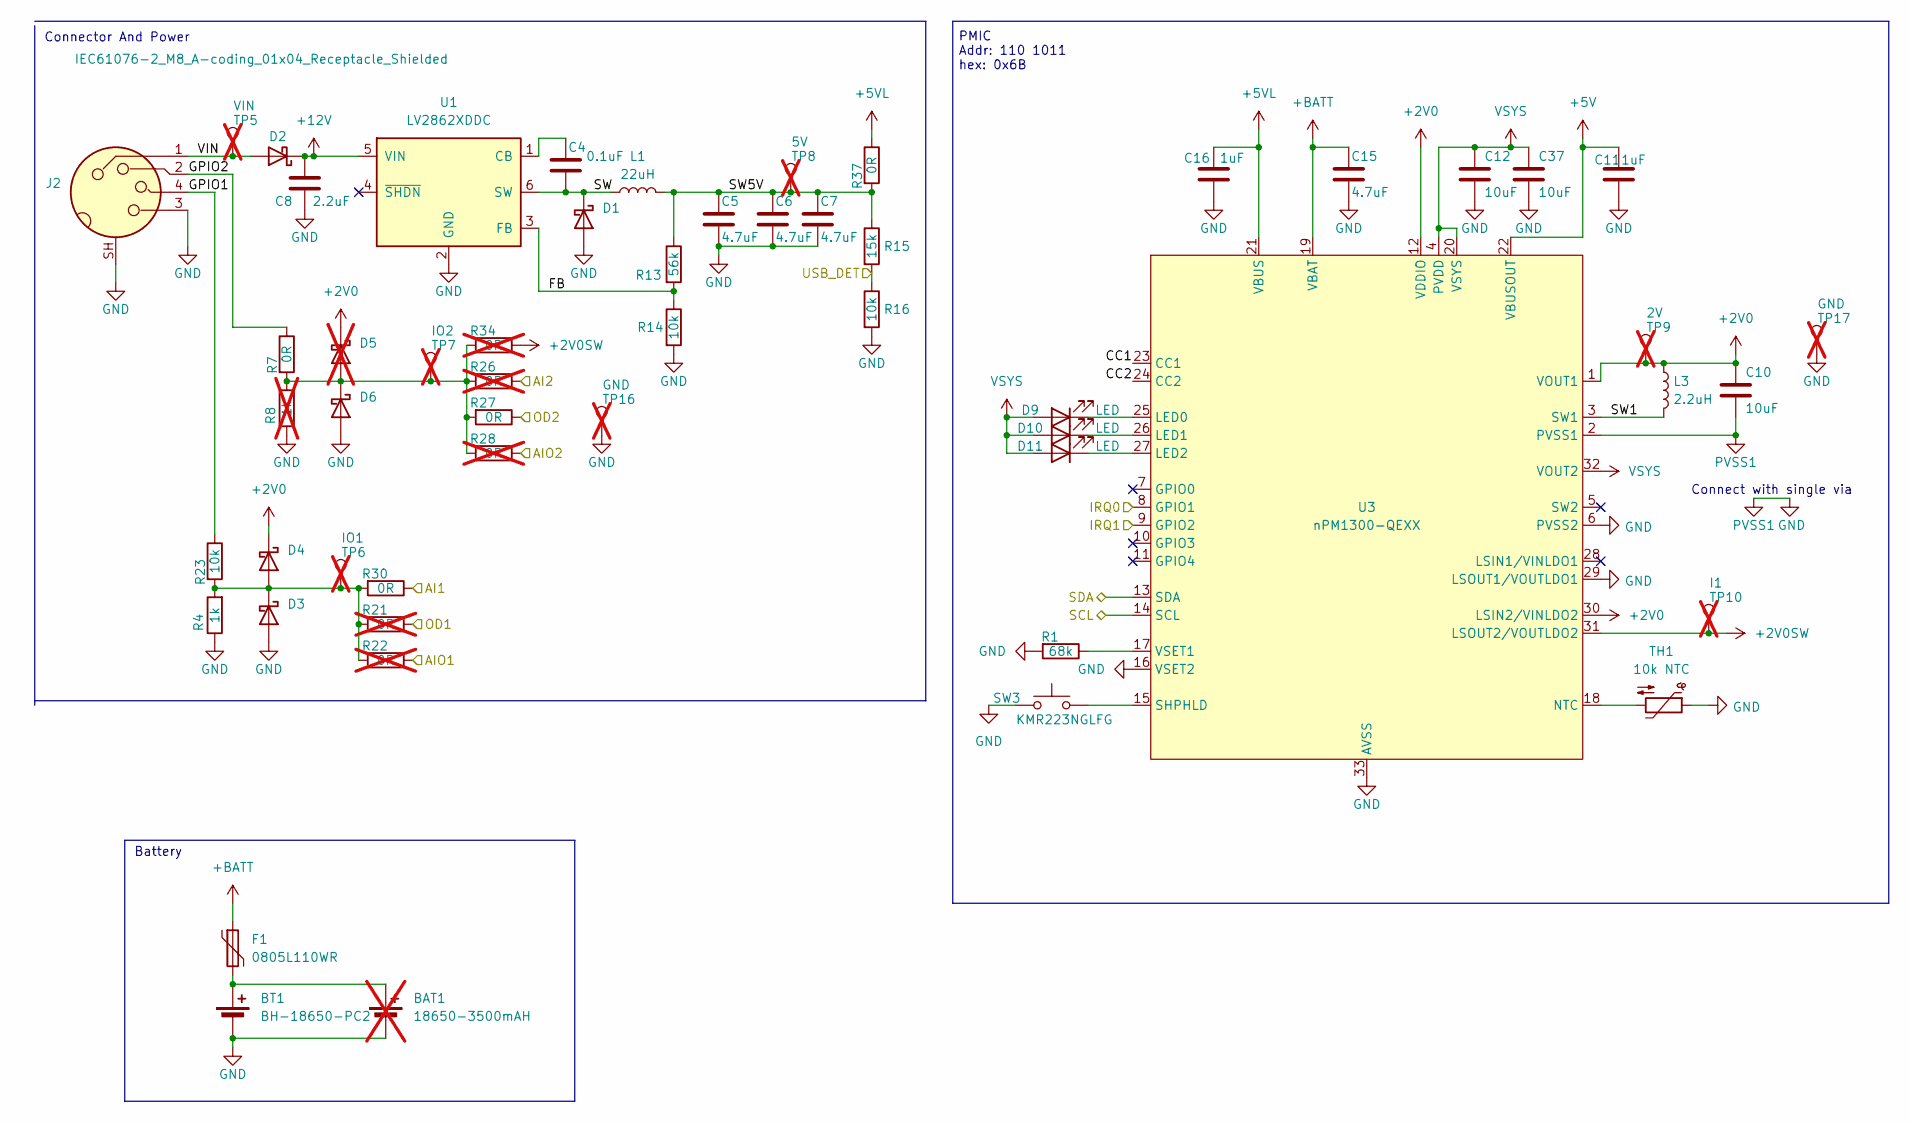
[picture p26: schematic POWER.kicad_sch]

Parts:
BAT1: 18650-3500mAH; not fitted
BT1: BH-18650-PC2; BatteryHolder_MPD_BH-18650-PC2; MPN BH-18650-PC2
C4: 0.1uF; C_0603_1608Metric
C5, C6, C7, C15: 4.7uF; C_0603_1608Metric
C8: 2.2uF; C_0805_2012Metric
C10, C12, C37: 10uF; C_0805_2012Metric
C11, C16: 1uF; C_0603_1608Metric
D1, D2: MSS1P3L-M3/89A; D_MicroSMP_AK; MPN MSS1P3L-M3/89A
D3, D4, D6: SD0603S040S0R2; D_0603_1608Metric; MPN SD0603S040S0R2
D5: SD0603S040S0R2; D_0603_1608Metric; MPN SD0603S040S0R2; not fitted
D9, D10, D11: LED; LED_0603_1608Metric; MPN LG L29K-G2J1-24-Z
F1: 0805L110WR; Fuse_0805_2012Metric; MPN 0805L110WR
J2: IEC61076-2_M8_A-coding_01x04_Receptacle_Shielded; STEWART_SS-12800-004_M8_04_Socket_Right_Angle; MPN SS-12800-004
L1: 22uH; L_Abracon_AMDLA4020S; MPN AMDLA4020S-220MT
L3: 2.2uH; L_1008_2520Metric; MPN CVH252009-2R2M
R1: 68k; R_0603_1608Metric
R4: 1k; R_0603_1608Metric
R7, R27, R30, R37: 0R; R_0603_1608Metric
R8: 1k; R_0603_1608Metric; not fitted
R13: 56k; R_0603_1608Metric
R14, R16, R23: 10k; R_0603_1608Metric
R15: 15k; R_0603_1608Metric
R21, R22, R26, R28, R34: 0R; R_0603_1608Metric; not fitted
SW3: KMR223NGLFG; SW_Push_1P1T_NO_CK_KMR2; MPN KMR223GLFG
TH1: 10k NTC; R_0603_1608Metric; MPN NTCG163JF103FT1
TP5: VIN; TestPoint_Pad_D1.0mm; not fitted
TP6: IO1; TestPoint_Pad_D1.0mm; not fitted
TP7: IO2; TestPoint_Pad_D1.0mm; not fitted
TP8: 5V; TestPoint_Pad_D1.0mm; not fitted
TP9: 2V; TestPoint_Pad_D1.0mm; not fitted
TP10: I1; TestPoint_Pad_D1.0mm; not fitted
TP16, TP17: GND; TestPoint_Pad_D1.0mm; not fitted
U1: LV2862XDDC; SOT-23-6; MPN LV2862XLVDDCR
U3: nPM1300-QEXX; QFN-32-1EP_5x5mm_P0.5mm_EP3.6x3.6mm_ThermalVias; MPN nPM1300-QEAA-R7

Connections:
+2V0: C10.1, D4.1 (K), D5.1 (K), L3.1, TP9.1, U3.1 (VOUT1), U3.12 (VDDIO), U3.30 (LSIN2/VINLDO2); also elsewhere on the board
+2V0SW: R34.1, TP10.1, U3.31 (LSOUT2/VOUTLDO2)
+5V: C11.1, U3.22 (VBUSOUT)
+5VL: C16.1, R37.1, U3.21 (VBUS)
+12V: C8.1, D2.1 (K), U1.5 (VIN); also elsewhere on the board
+BATT: C15.1, F1.1, U3.19 (VBAT); also elsewhere on the board
/GAS_SENSOR/AIN2: R30.1; also elsewhere on the board
/GAS_SENSOR/AIN3: R26.1; also elsewhere on the board
/POWER/CC1: U3.23 (CC1)
/POWER/CC2: U3.24 (CC2)
/POWER/FB: R13.2, R14.1, U1.3 (FB)
/POWER/GPIO1: J2.4, R23.1
/POWER/GPIO2: J2.2, R7.1
/POWER/OD1: R21.1; also elsewhere on the board
/POWER/OD2: R27.1; also elsewhere on the board
/POWER/SW: C4.2, D1.1 (K), L1.1, U1.6 (SW)
/POWER/SW1: L3.2, U3.3 (SW1)
/POWER/SW5V: C5.1, C6.1, C7.1, L1.2, R13.1, R15.1, R37.2, TP8.1
/POWER/VIN: D2.2 (A), J2.1, TP5.1
GND: BAT1.2 (-), BT1.2 (-), C5.2, C6.2, C7.2, C8.2, C10.2, C11.2, C12.2, C15.2, C16.2, C37.2, D1.2 (A), D3.2 (A), D6.2 (A), J2.3, J2.SH, R1.2, R4.1, R8.1, R14.2, R16.2, SW3.2, TH1.1, TP16.1, TP17.1, U1.2 (GND), U3.2 (PVSS1), U3.6 (PVSS2), U3.16 (VSET2), U3.29 (LSOUT1/VOUTLDO1), U3.33 (AVSS); also elsewhere on the board
unnamed: BAT1.1 (+), BT1.1 (+), F1.2
unnamed: D3.1 (K), D4.2 (A), R4.2, R21.2, R22.2, R23.2, R30.2, TP6.1
unnamed: D5.2 (A), D6.1 (K), R7.2, R8.2, R26.2, R27.2, R28.2, R34.2, TP7.1
unnamed: D9.1 (K), U3.25 (LED0)
unnamed: D10.1 (K), U3.26 (LED1)
unnamed: D11.1 (K), U3.27 (LED2)
unnamed: C4.1, U1.1 (CB)
unnamed: TH1.2, U3.18 (NTC)
unnamed: SW3.1, U3.15 (SHPHLD)
unnamed: R1.1, U3.17 (VSET1)
P0.05: R15.2, R16.1; also elsewhere on the board
P0.11: U3.8 (GPIO1); also elsewhere on the board
P0.12: U3.9 (GPIO2); also elsewhere on the board
P0.15/AIN2: R28.1; also elsewhere on the board
P0.16/AIN3: R22.1; also elsewhere on the board
P0.28: U3.13 (SDA); also elsewhere on the board
P0.29: U3.14 (SCL); also elsewhere on the board
VCC: C12.1, C37.1, D9.2 (A), D10.2 (A), D11.2 (A), U3.4 (PVDD), U3.20 (VSYS), U3.32 (VOUT2); also elsewhere on the board

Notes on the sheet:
Connect with single via
Addr: 110 1011 hex: 0x6B
Connector And Power
PMIC
Battery

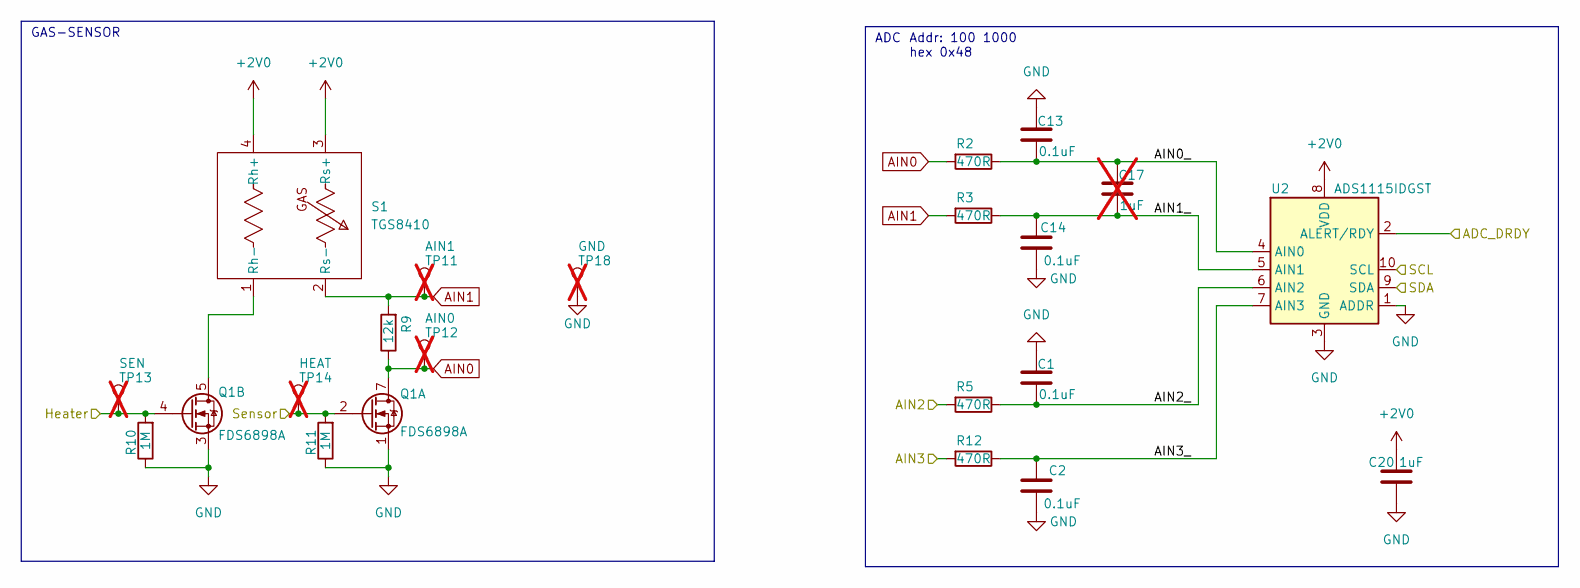
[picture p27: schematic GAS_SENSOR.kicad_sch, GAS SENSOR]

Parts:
C1, C2, C13, C14: 0.1uF; C_0603_1608Metric
C17: 1uF; C_0603_1608Metric; not fitted
C20: 1uF; C_0603_1608Metric
Q1: FDS6898A; SOIC-8_3.9x4.9mm_P1.27mm; MPN FDS6898A
R2, R3, R5, R12: 470R; R_0603_1608Metric
R9: 12k; R_0603_1608Metric
R10, R11: 1M; R_0603_1608Metric
S1: TGS8410; MPN TGS8410
TP11: AIN1; TestPoint_Pad_D1.0mm; not fitted
TP12: AIN0; TestPoint_Pad_D1.0mm; not fitted
TP13: SEN; TestPoint_Pad_D1.0mm; not fitted
TP14: HEAT; TestPoint_Pad_D1.0mm; not fitted
TP18: GND; TestPoint_Pad_D1.0mm; not fitted
U2: ADS1115IDGST; TSSOP-10_3x3mm_P0.5mm; MPN ADS1115IDGSR

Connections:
+2V0: C20.1, S1.3 (Rs+), S1.4 (Rh+), U2.8 (VDD); also elsewhere on the board
/GAS_SENSOR/AIN0_: C13.2, C17.1, R2.1, U2.4 (AIN0)
/GAS_SENSOR/AIN1_: C14.2, C17.2, R3.1, U2.5 (AIN1)
/GAS_SENSOR/AIN2: R5.2; also elsewhere on the board
/GAS_SENSOR/AIN2_: C1.2, R5.1, U2.6 (AIN2)
/GAS_SENSOR/AIN3: R12.2; also elsewhere on the board
/GAS_SENSOR/AIN3_: C2.2, R12.1, U2.7 (AIN3)
AIN0: Q1.7 (D1), Q1.8 (D1), R2.2, R9.1, TP12.1
AIN1: R3.2, R9.2, S1.2 (Rs-), TP11.1
GND: C1.1, C2.1, C13.1, C14.1, C20.2, Q1.1 (S1), Q1.3 (S2), R10.1, R11.1, TP18.1, U2.1 (ADDR), U2.3 (GND); also elsewhere on the board
unnamed: Q1.5 (D2), Q1.6 (D2), S1.1 (Rh-)
P0.26: U2.2 (ALERT/RDY); also elsewhere on the board
P0.27: Q1.2 (G1), R11.2, TP14.1; also elsewhere on the board
P0.28: U2.9 (SDA); also elsewhere on the board
P0.29: U2.10 (SCL); also elsewhere on the board
P0.31: Q1.4 (G2), R10.2, TP13.1; also elsewhere on the board

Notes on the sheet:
ADC
Addr: 100 1000 hex 0x48
GAS-SENSOR

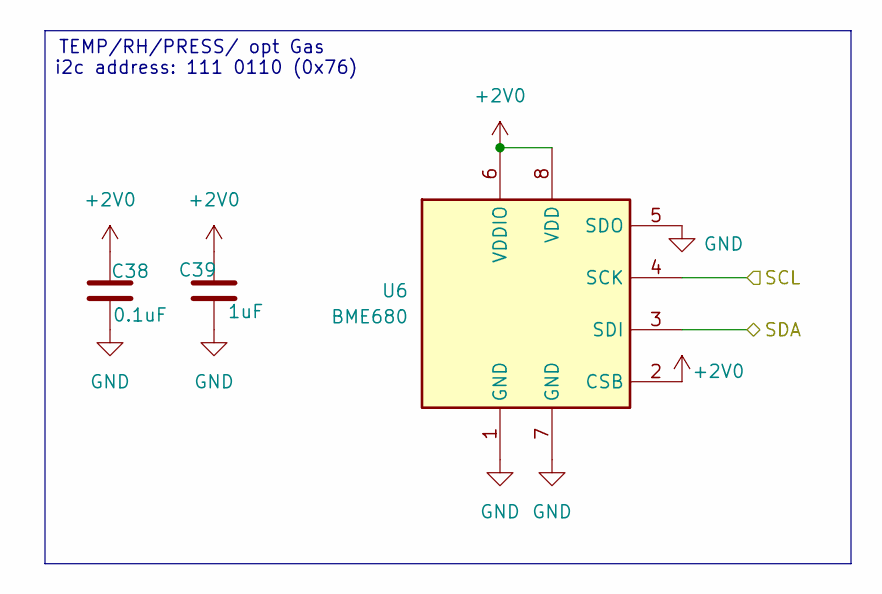
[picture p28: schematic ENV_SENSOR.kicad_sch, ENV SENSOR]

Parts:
C38: 0.1uF; C_0603_1608Metric
C39: 1uF; C_0603_1608Metric
U6: BME680; Bosch_LGA-8_3x3mm_P0.8mm_ClockwisePinNumbering; MPN BME680

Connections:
+2V0: C38.1, C39.1, U6.2 (CSB), U6.6 (VDDIO), U6.8 (VDD); also elsewhere on the board
GND: C38.2, C39.2, U6.1 (GND), U6.5 (SDO), U6.7 (GND); also elsewhere on the board
P0.28: U6.3 (SDI); also elsewhere on the board
P0.29: U6.4 (SCK); also elsewhere on the board

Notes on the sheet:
i2c address: 111 0110 (0x76)
TEMP/RH/PRESS/ opt Gas

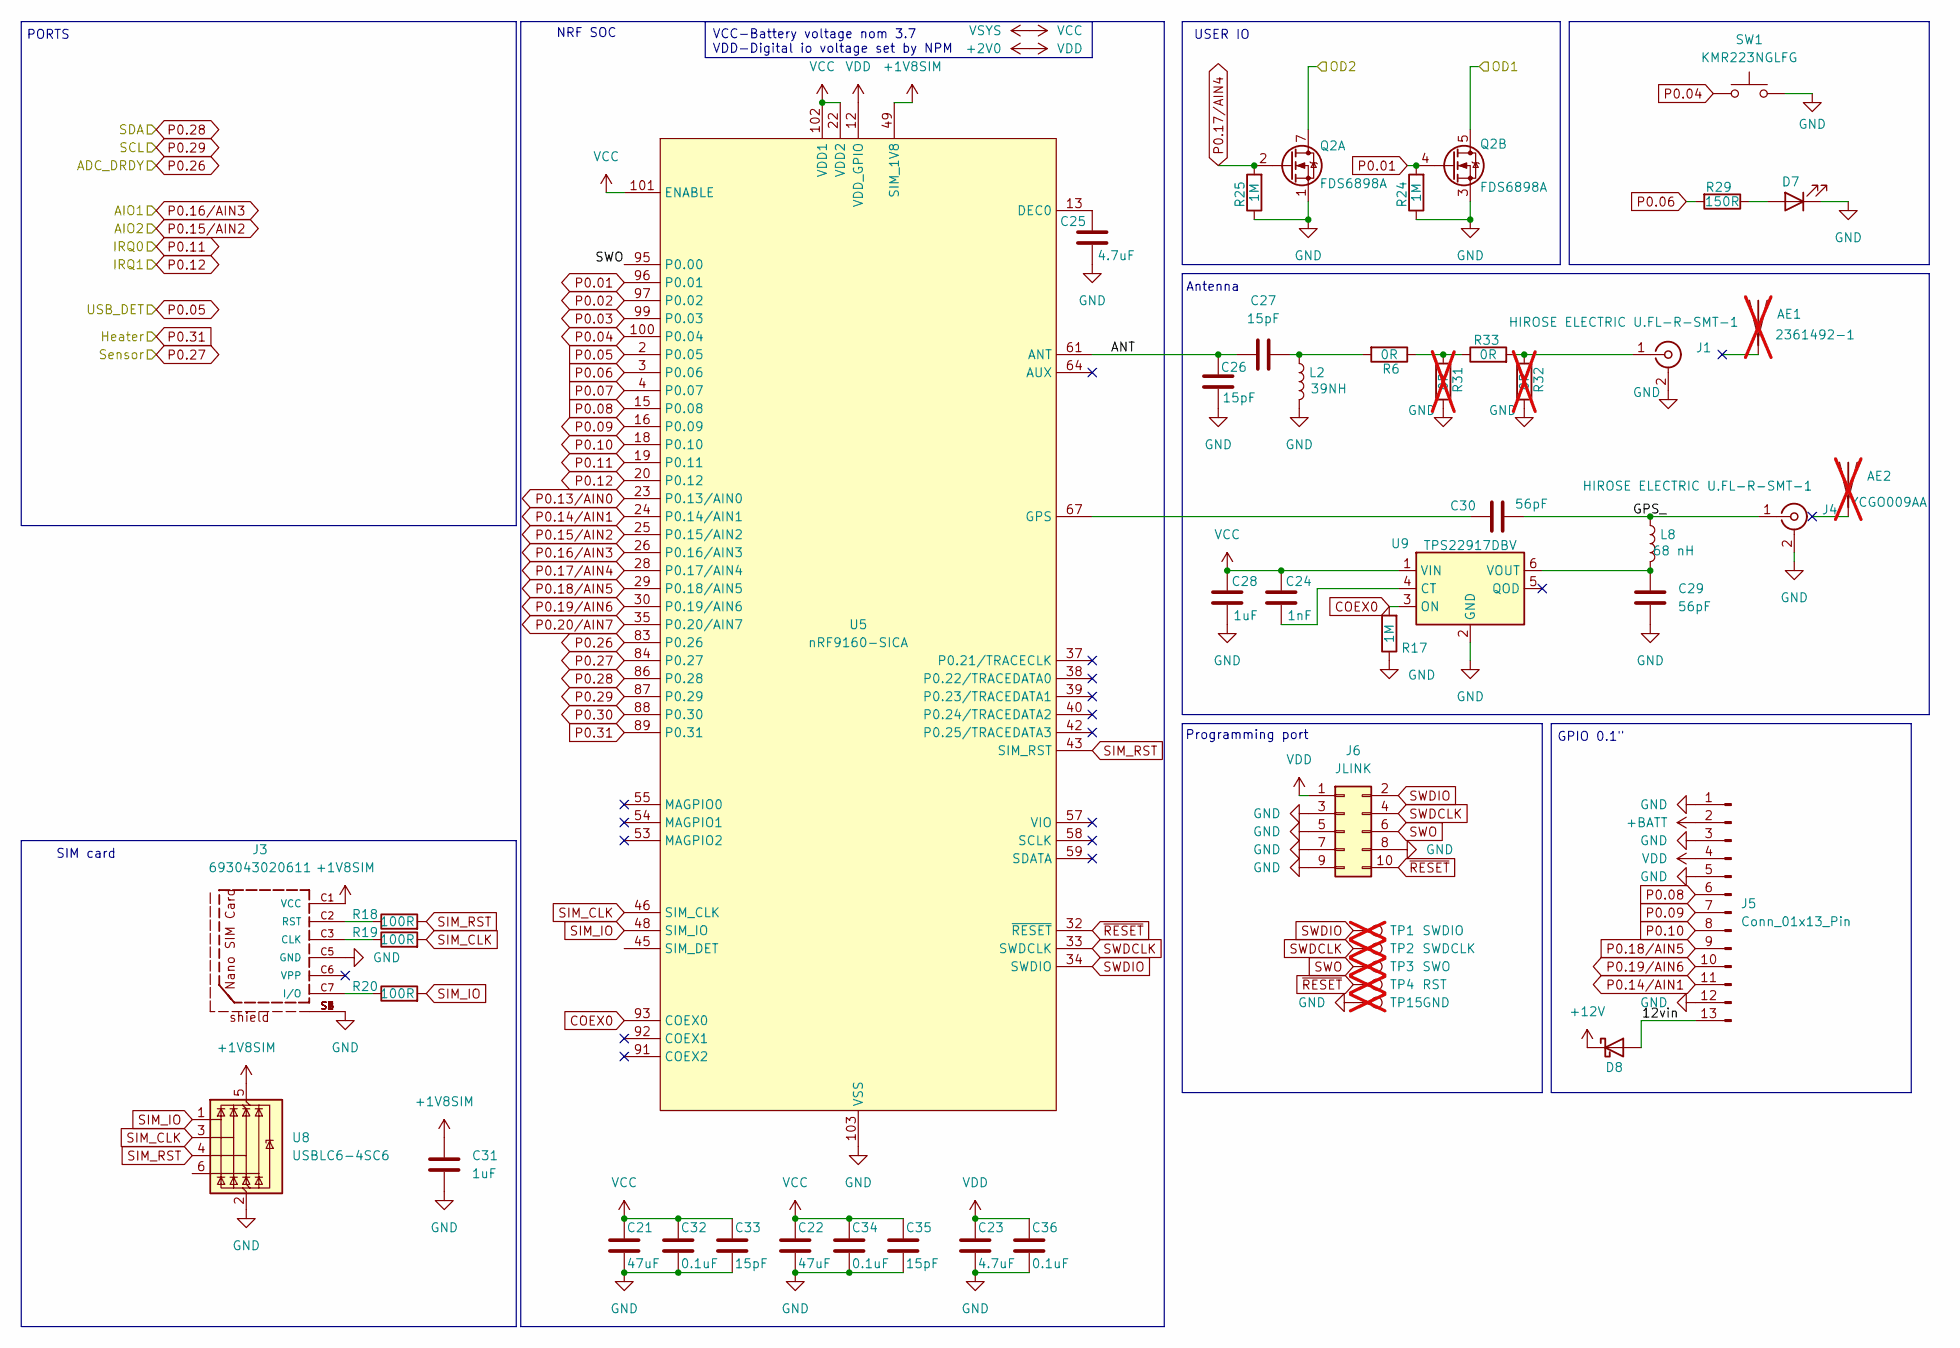
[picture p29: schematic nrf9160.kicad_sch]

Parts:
AE1: 2361492-1; MPN 2361492-1; not fitted
AE2: YCGO009AA; not fitted
C21, C22: 47uF; C_0805_2012Metric
C23, C25: 4.7uF; C_0603_1608Metric
C24: 1nF; C_0603_1608Metric
C26, C27, C33, C35: 15pF; C_0402_1005Metric_Sqr; MPN VJ0402D150FXCAJ
C28, C31: 1uF; C_0603_1608Metric
C29, C30: 56pF; C_0402_1005Metric_Sqr; MPN CBR04C560F1GAC
C32, C34, C36: 0.1uF; C_0603_1608Metric
D7: LG L29K-G2J1-24-Z; LED_0603_1608Metric; MPN LG L29K-G2J1-24-Z
D8: MSS1P3L-M3/89A; D_MicroSMP_AK; MPN MSS1P3L-M3/89A
J1, J4: HIROSE ELECTRIC U.FL-R-SMT-1; U.FL_Hirose_U.FL-R-SMT-1_Vertical; MPN U.FL-R-SMT-1
J3: 693043020611; PART-NUMBER 693043020611
J5: Conn_01x13_Pin; PinHeader_1x13_P2.54mm_Vertical
J6: JLINK; SEXY_pinpogo; MPN BD125-10-A-0305-0580-L-B
L2: 39NH; C_0402_1005Metric_Sqr; MPN LQW15AN39NJ8ZD
L8: 68 nH; C_0402_1005Metric_Sqr; MPN LQW15AN68NG0ZD
Q2: FDS6898A; SOIC-8_3.9x4.9mm_P1.27mm; MPN FDS6898A
R6, R33: 0R; R_0402_1005Metric
R17, R24, R25: 1M; R_0603_1608Metric
R18, R19, R20: 100R; R_0603_1608Metric
R29: 150R; R_0603_1608Metric
R31, R32: 0R; R_0402_1005Metric; not fitted
SW1: KMR223NGLFG; SW_Push_1P1T_NO_CK_KMR2; MPN KMR223GLFG
TP1: SWDIO; TestPoint_Pad_D1.0mm; not fitted
TP2: SWDCLK; TestPoint_Pad_D1.0mm; not fitted
TP3: SWO; TestPoint_Pad_D1.0mm; not fitted
TP4: RST; TestPoint_Pad_D1.0mm; not fitted
TP15: GND; TestPoint_Pad_D1.0mm; not fitted
U5: nRF9160-SICA; LGA_9160_16.0x10.5mm; MPN nRF9160-SICA-B1A-R7
U8: USBLC6-4SC6; SOT-23-6; MPN USBLC6-4SC6
U9: TPS22917DBV; SOT-23-6; MPN TPS22917DBVR

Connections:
+1V8SIM: C31.1, J3.C1 (VCC), U5.49 (SIM_1V8), U8.5 (VBUS)
+2V0: C23.1, C36.1, J5.4, J6.1, U5.12 (VDD_GPIO); also elsewhere on the board
+12V: D8.1 (K); also elsewhere on the board
+BATT: J5.2; also elsewhere on the board
/POWER/OD1: Q2.5 (D2), Q2.6 (D2); also elsewhere on the board
/POWER/OD2: Q2.7 (D1), Q2.8 (D1); also elsewhere on the board
/nrf9160/12vin: D8.2 (A), J5.13
/nrf9160/ANT: C26.1, C27.1, U5.61 (ANT)
/nrf9160/GPS_: C30.2, J4.1 (In), L8.1
COEX0: R17.2, U5.93 (COEX0), U9.3 (ON)
GND: C21.2, C22.2, C23.2, C25.2, C26.2, C28.2, C29.2, C31.2, C32.2, C33.2, C34.2, C35.2, C36.2, D7.1 (K), J1.2 (Ext), J3.C5 (GND), J3.S1, J3.S2, J3.S3, J3.S4, J3.S5, J3.S6, J4.2 (Ext), J5.1, J5.3, J5.5, J5.12, J6.3, J6.5, J6.7, J6.8, J6.9, L2.2, Q2.1 (S1), Q2.3 (S2), R17.1, R24.1, R25.1, R31.2, R32.2, SW1.2, TP15.1, U5.1 (GND_Shield), U5.5 (GND_Shield), U5.6 (GND_Shield), U5.7 (GND_Shield), U5.8 (GND_Shield), U5.9 (GND_Shield), U5.11 (GND_Shield), U5.14 (GND_Shield), U5.17 (GND_Shield), U5.21 (GND_Shield), U5.27 (GND_Shield), U5.31 (GND_Shield), U5.36 (GND_Shield), U5.41 (GND_Shield), U5.44 (GND_Shield), U5.47 (GND_Shield), U5.50 (GND_Shield), U5.52 (GND_Shield), U5.56 (GND_Shield), U5.60 (GND_Shield), U5.62 (GND_Shield), U5.63 (GND_Shield), U5.65 (GND_Shield), U5.66 (GND_Shield), U5.68 (GND_Shield), U5.69 (GND_Shield), U5.72 (GND_Shield), U5.74 (GND_Shield), U5.75 (GND_Shield), U5.76 (GND_Shield), U5.77 (GND_Shield), U5.78 (GND_Shield), U5.79 (GND_Shield), U5.80 (GND_Shield), U5.81 (GND_Shield), U5.82 (GND_Shield), U5.85 (GND_Shield), U5.90 (GND_Shield), U5.94 (GND_Shield), U5.98 (GND_Shield), U5.103 (VSS), U8.2 (GND), U9.2 (GND); also elsewhere on the board
unnamed: C27.2, L2.1, R6.2
unnamed: D7.2 (A), R29.1
unnamed: J1.1 (In), R32.1, R33.2
unnamed: J3.C3 (CLK), R19.1
unnamed: J3.C7 (I/O), R20.1
unnamed: J3.C2 (RST), R18.1
unnamed: R6.1, R31.1, R33.1
unnamed: C25.1, U5.13 (DEC0)
unnamed: C30.1, U5.67 (GPS)
unnamed: C24.2, U9.4 (CT)
unnamed: C29.1, L8.2, U9.6 (VOUT)
P0.01: Q2.4 (G2), R24.2, U5.96 (P0.01)
P0.02: U5.97 (P0.02)
P0.03: U5.99 (P0.03)
P0.04: SW1.1, U5.100 (P0.04)
P0.05: U5.2 (P0.05); also elsewhere on the board
P0.06: R29.2, U5.3 (P0.06)
P0.07: U5.4 (P0.07)
P0.08: J5.6, U5.15 (P0.08)
P0.09: J5.7, U5.16 (P0.09)
P0.10: J5.8, U5.18 (P0.10)
P0.11: U5.19 (P0.11); also elsewhere on the board
P0.12: U5.20 (P0.12); also elsewhere on the board
P0.13/AIN0: U5.23 (P0.13/AIN0)
P0.14/AIN1: J5.11, U5.24 (P0.14/AIN1)
P0.15/AIN2: U5.25 (P0.15/AIN2); also elsewhere on the board
P0.16/AIN3: U5.26 (P0.16/AIN3); also elsewhere on the board
P0.17/AIN4: Q2.2 (G1), R25.2, U5.28 (P0.17/AIN4)
P0.19/AIN6: J5.10, U5.30 (P0.19/AIN6)
P0.20/AIN7: U5.35 (P0.20/AIN7)
P0.26: U5.83 (P0.26); also elsewhere on the board
P0.27: U5.84 (P0.27); also elsewhere on the board
P0.28: U5.86 (P0.28); also elsewhere on the board
P0.29: U5.87 (P0.29); also elsewhere on the board
P0.30: U5.88 (P0.30)
P0.31: U5.89 (P0.31); also elsewhere on the board
SIM_CLK: R19.2, U5.46 (SIM_CLK), U8.3 (I/O2)
SIM_IO: R20.2, U5.48 (SIM_IO), U8.1 (I/O1)
SIM_RST: R18.2, U5.43 (SIM_RST), U8.4 (I/O3)
SWDCLK: J6.4, TP2.1, U5.33 (SWDCLK)
SWDIO: J6.2, TP1.1, U5.34 (SWDIO)
SWO: J6.6, TP3.1, U5.95 (P0.00)
VCC: C21.1, C22.1, C24.1, C28.1, C32.1, C33.1, C34.1, C35.1, U5.22 (VDD2), U5.101 (ENABLE), U5.102 (VDD1), U9.1 (VIN); also elsewhere on the board
~RESET: J6.10, TP4.1, U5.32 (~RESET)

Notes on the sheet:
Programming port
NRF SOC
USER IO
PORTS
SIM card
Antenna
GPIO 0.1"
VCC-Battery voltage nom 3.7 VDD-Digital io voltage set by NPM

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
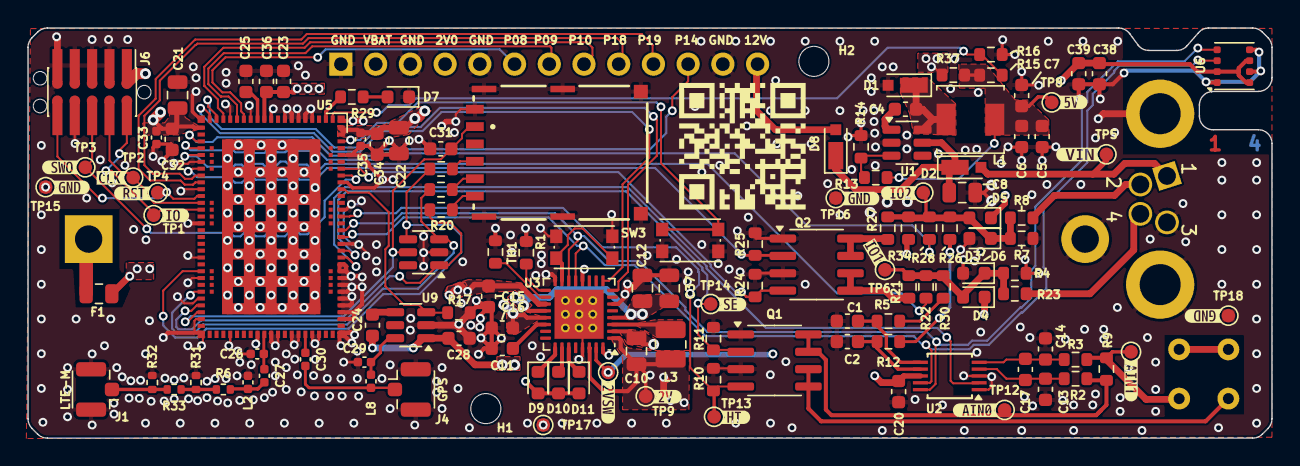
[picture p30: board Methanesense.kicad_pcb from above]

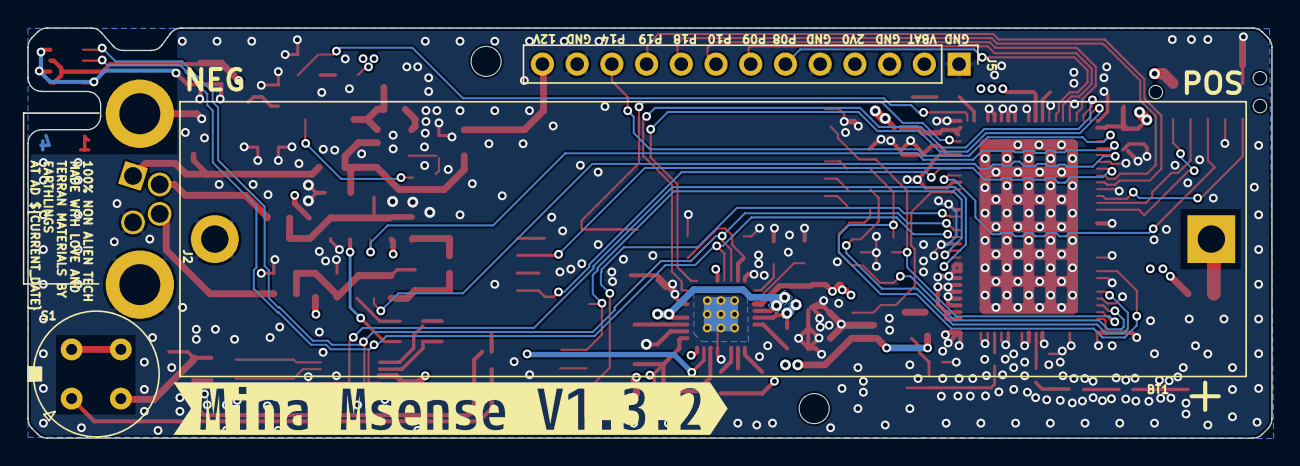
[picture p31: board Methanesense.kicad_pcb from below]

Board: 4 copper layers, 91.0 x 30.0 mm, 144 parts (5 on the bottom side), 79 nets.

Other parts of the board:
kibuzzard-680A1FD4: G***; kibuzzard-680A1FD4
kibuzzard-680B6FC7: G***; kibuzzard-680B6FC7
kibuzzard-680B70A9: G***; kibuzzard-680B70A9
kibuzzard-680B70C8: G***; kibuzzard-680B70C8
kibuzzard-680B70F6: G***; kibuzzard-680B70F6
kibuzzard-680B71B4, kibuzzard-680B71B4#2: G***; kibuzzard-680B71B4
kibuzzard-680B72A0: G***; kibuzzard-680B72A0
kibuzzard-680B72CB: G***; kibuzzard-680B72CB
kibuzzard-680B72EC: G***; kibuzzard-680B72EC
kibuzzard-680B73BF: G***; kibuzzard-680B73BF
kibuzzard-680B73D9: G***; kibuzzard-680B73D9
kibuzzard-680B701D: G***; kibuzzard-680B701D
kibuzzard-680B712B: G***; kibuzzard-680B712B
kibuzzard-680B714A: G***; kibuzzard-680B714A
kibuzzard-680B715D: G***; kibuzzard-680B715D
kibuzzard-680B7297: G***; kibuzzard-680B7297
kibuzzard-680B7325: G***; kibuzzard-680B7325

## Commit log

2024-08-01 Allmost there
    [ENV_SENSOR.kicad_sch, GAS_SENSOR.kicad_sch, Methanesense.kicad_pcb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]
2024-08-05 NRF footprint change
    [ENV_SENSOR.kicad_sch, GAS_SENSOR.kicad_sch, Methanesense.kicad_pcb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]
2024-08-12 Rev 2.0.0
    [GAS_SENSOR.kicad_sch, Methanesense.kicad_pcb, Methanesense.kicad_sch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]
2025-04-16 rev 1.2
    [ENV_SENSOR.kicad_sch, GAS_SENSOR.kicad_sch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]
2025-04-25 Feat: Rev 1.3
    [ENV_SENSOR.kicad_sch, GAS_SENSOR.kicad_sch, Methanesense.kicad_pcb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]
2025-04-28 Feat: Cleaning up schems
    [POWER.kicad_sch, nrf9160.kicad_sch]
2025-08-20 Feat: Prettified repo Readme
    [Enclosure_board_132 v26.step, GAS_SENSOR.kicad_sch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]
2025-08-21 Fix: Trying to correct lower case error
2025-08-21 Fix: CI Push
    [Methanesense-B_Cu.gbr, Methanesense-B_Mask.gbr, Methanesense-B_Paste.gbr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]
2025-08-21 Fix: Ibom work
    [Methanesense-B_Cu.gbr, Methanesense-B_Mask.gbr, Methanesense-B_Paste.gbr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]
2025-08-22 Fix: Update battery size README.md
